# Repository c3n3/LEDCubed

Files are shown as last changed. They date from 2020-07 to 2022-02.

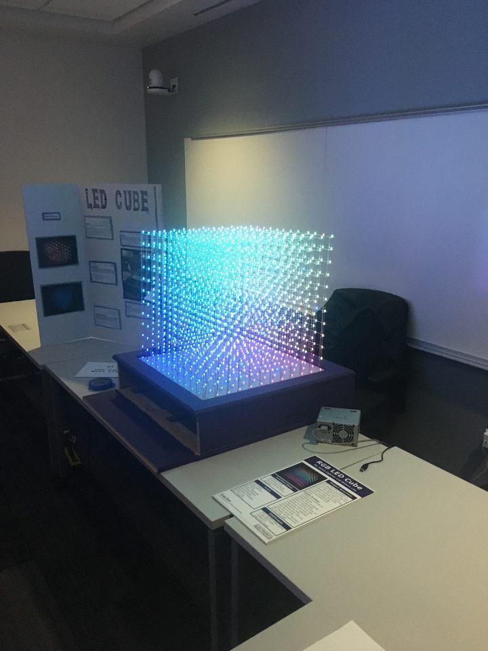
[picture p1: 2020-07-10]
kicad/LED_Cube/Documentation/Cube.jpg

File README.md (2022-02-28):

# LEDCubed
LED^3

Hello person who wishes to learn the cube's ways! This will be a BRIEF introduction... Basically the situation is as follows: we have a cube, it is a 12 x 12 x 12 cube of RGB LEDs, we have this newly (but probably old when your reading this) created softare architecture that will hopefully stand the test of time (you decide). The things you want to look into are:
  
  App.h -> this contains the workings for how you make an 'App' for the cube, these can be animations, games, anything...
  The contained class is to be used as an abstract class and not to be used directly.
  
  Basic_Functions.h -> these are the low level functions that allow you to turn LEDs on and change their colors and such

If you fully understand what is in those two files you can start making apps. If you have trouble understanding what is going on just contact me, Caden Churchman, if you can possibly get my information (I'm definitly not writting it here).  

*************************
If you want to bypass the whole structure of the code, feel free to comment out the main loop of arduino and just test stuff there. (Thats probably the best way to learn what the heck is going on)
*************************

TODO:
  - Nest (Wrires)

  - More cool animations

  - 3d tetris

  - 3d minesweeper <----------------------------------- NEXT

  - oscilating 3d graph

  - Glass box

  - Maze/DoomMaze

Done:
  - Add links or files for the KiCad files that made the circuitry

  - Optimize code - Done?

  - Rolling Text Display - Done: TypeEngine

  - Stand - Done
  
  - Power inside stand - Done

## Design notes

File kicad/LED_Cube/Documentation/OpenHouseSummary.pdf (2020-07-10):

Electronics Design Club LED Cube Project Summary

Objective
To create a 12x12x12 pixel, full-color, three-dimensional display.

Problem
Three-dimensional displays are ideal for any application dealing with the representation of real-world objects. These displays are very hard to build because they require light sources in a three-dimensional (3D) arrangement that are visible from any angle. Adding gradient or color effects to such a display further complicates the design because these features require a high degree of electrical manipulation.

Research
Extensive research was done on 3D displays to determine the most feasible design. The LED cube design was deemed most appropriate. Other types of 3D displays exist. One alternative design uses a fan-like structure with lights on spinning arms. This design takes advantage of the persistence of vision (POV) effect to generate 3D images. This design was deemed infeasible because of its mechanical intricacy.

Constraints
E-Club’s LED Cube was designed and constructed under the following constraints:
- 12x12x12 resolution
- Full-color operation
- No perceptible flicker
- Bright enough to be visible in a well-lit room
- Frame rate above 27 Hz
- Cost-effective

Solution
E-Club’s LED cube satisfies all of the original design criteria. It consists of a 12x12x12 matrix of full-color LEDs, multiplexing circuitry, and a microcontroller. The microcontroller is able to render images on the display via the multiplexing circuitry. Although the LEDs are multiplexed, they are still bright enough to be seen in virtually all lighting conditions.

Conclusion
The Electronics Design Club has constructed a full-color LED Cube consisting of 1728 multiplexed LEDs. This project is the result of two years of work by a team of students. The completion of the cube required extensive skill in soldering, woodworking, circuit design, programming, and troubleshooting. The end result is an impressive 3D display that showcases both the technical ability and creativity of K-State engineering students.

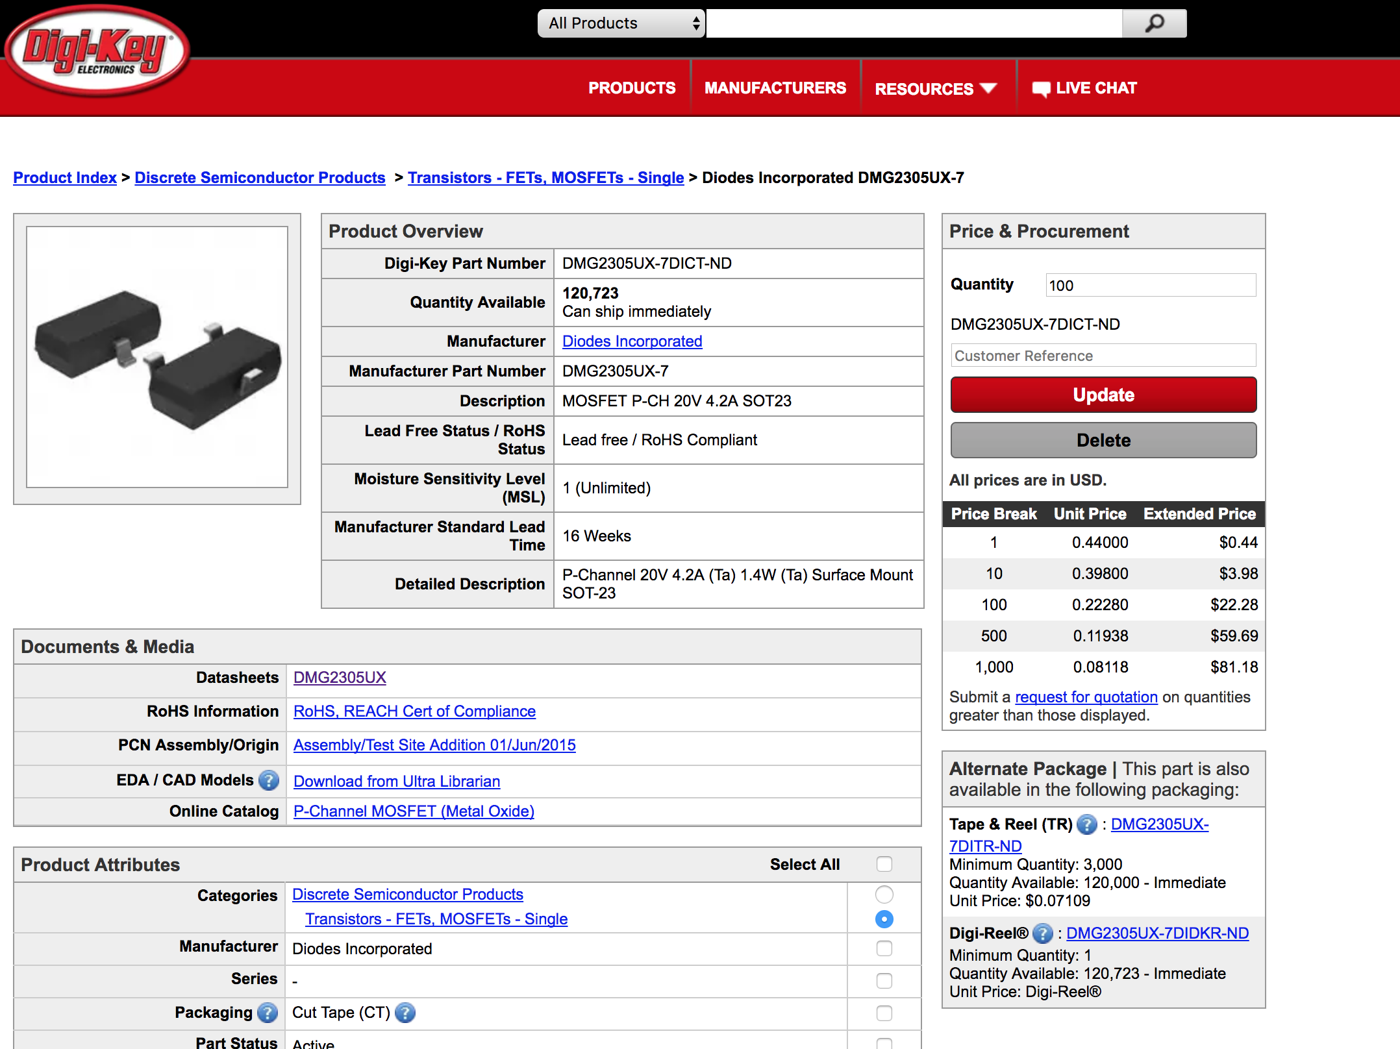
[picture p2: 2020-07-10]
kicad/LED_Cube/Documentation/Screen Shot 2017-12-16 at 11.59.10 PM.png

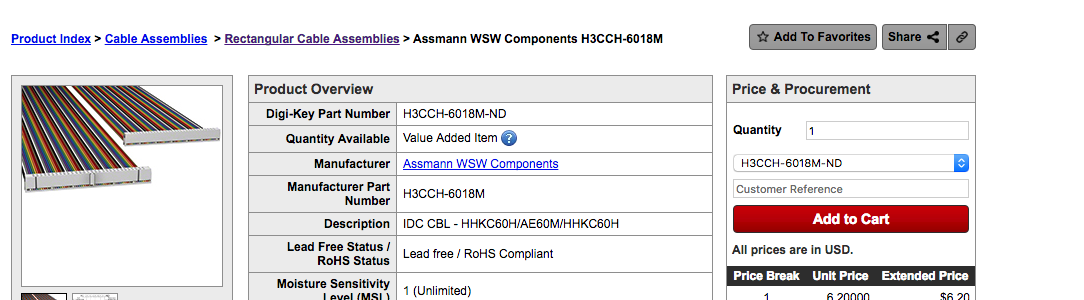
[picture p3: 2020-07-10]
kicad/LED_Cube/Screen Shot 2018-01-17 at 7.31.01 PM.png

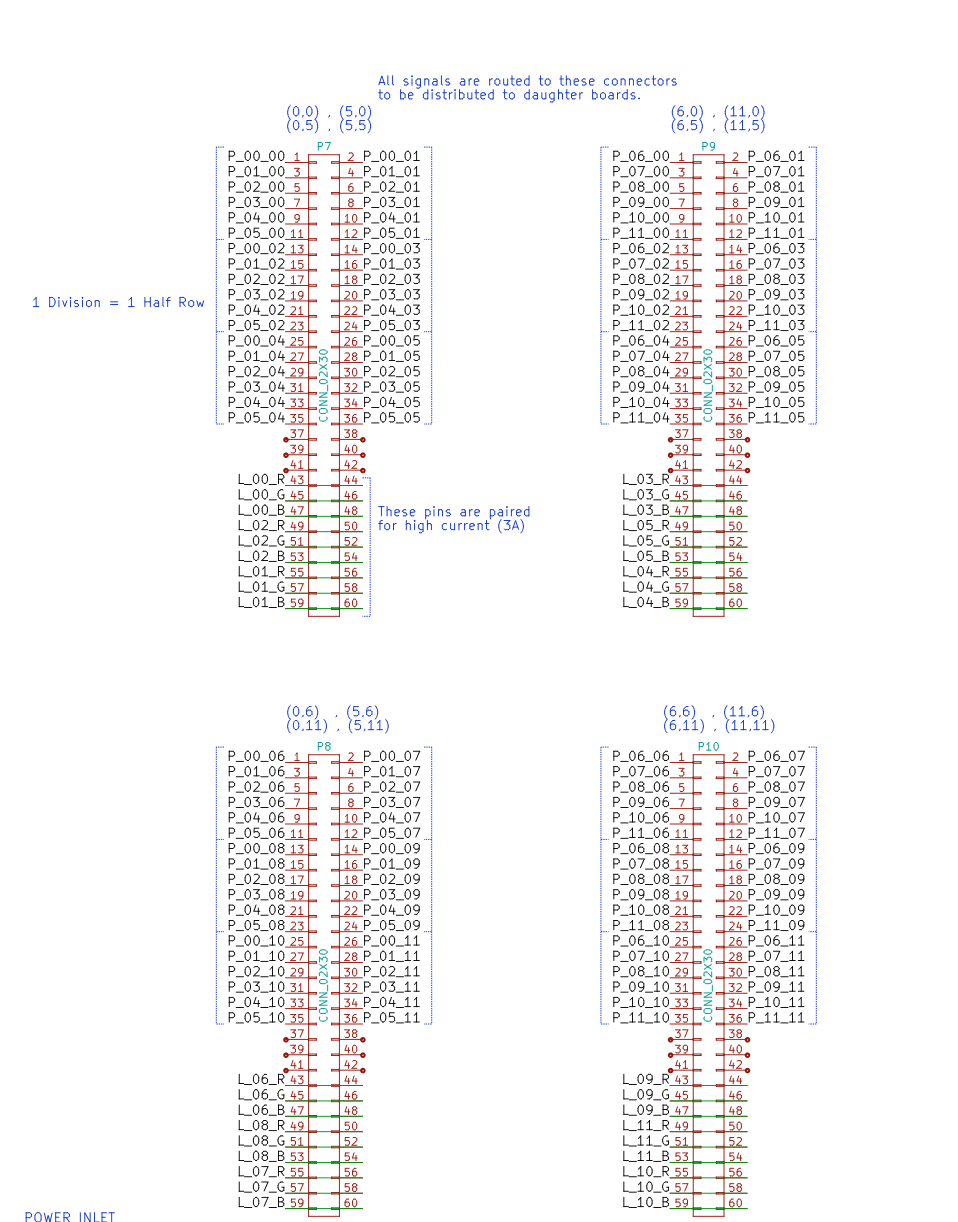
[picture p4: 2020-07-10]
kicad/LED_Cube/Screen Shot 2018-01-25 at 6.02.30 PM.png

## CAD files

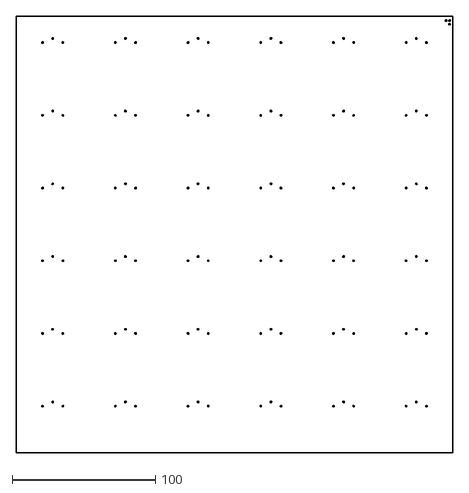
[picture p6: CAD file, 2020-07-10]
kicad/LED_Cube/CAD/LED Full Base TR.dxf
304.8 x 304.8

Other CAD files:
kicad/LED_Cube/CAD/LED Full Base TR.dwg

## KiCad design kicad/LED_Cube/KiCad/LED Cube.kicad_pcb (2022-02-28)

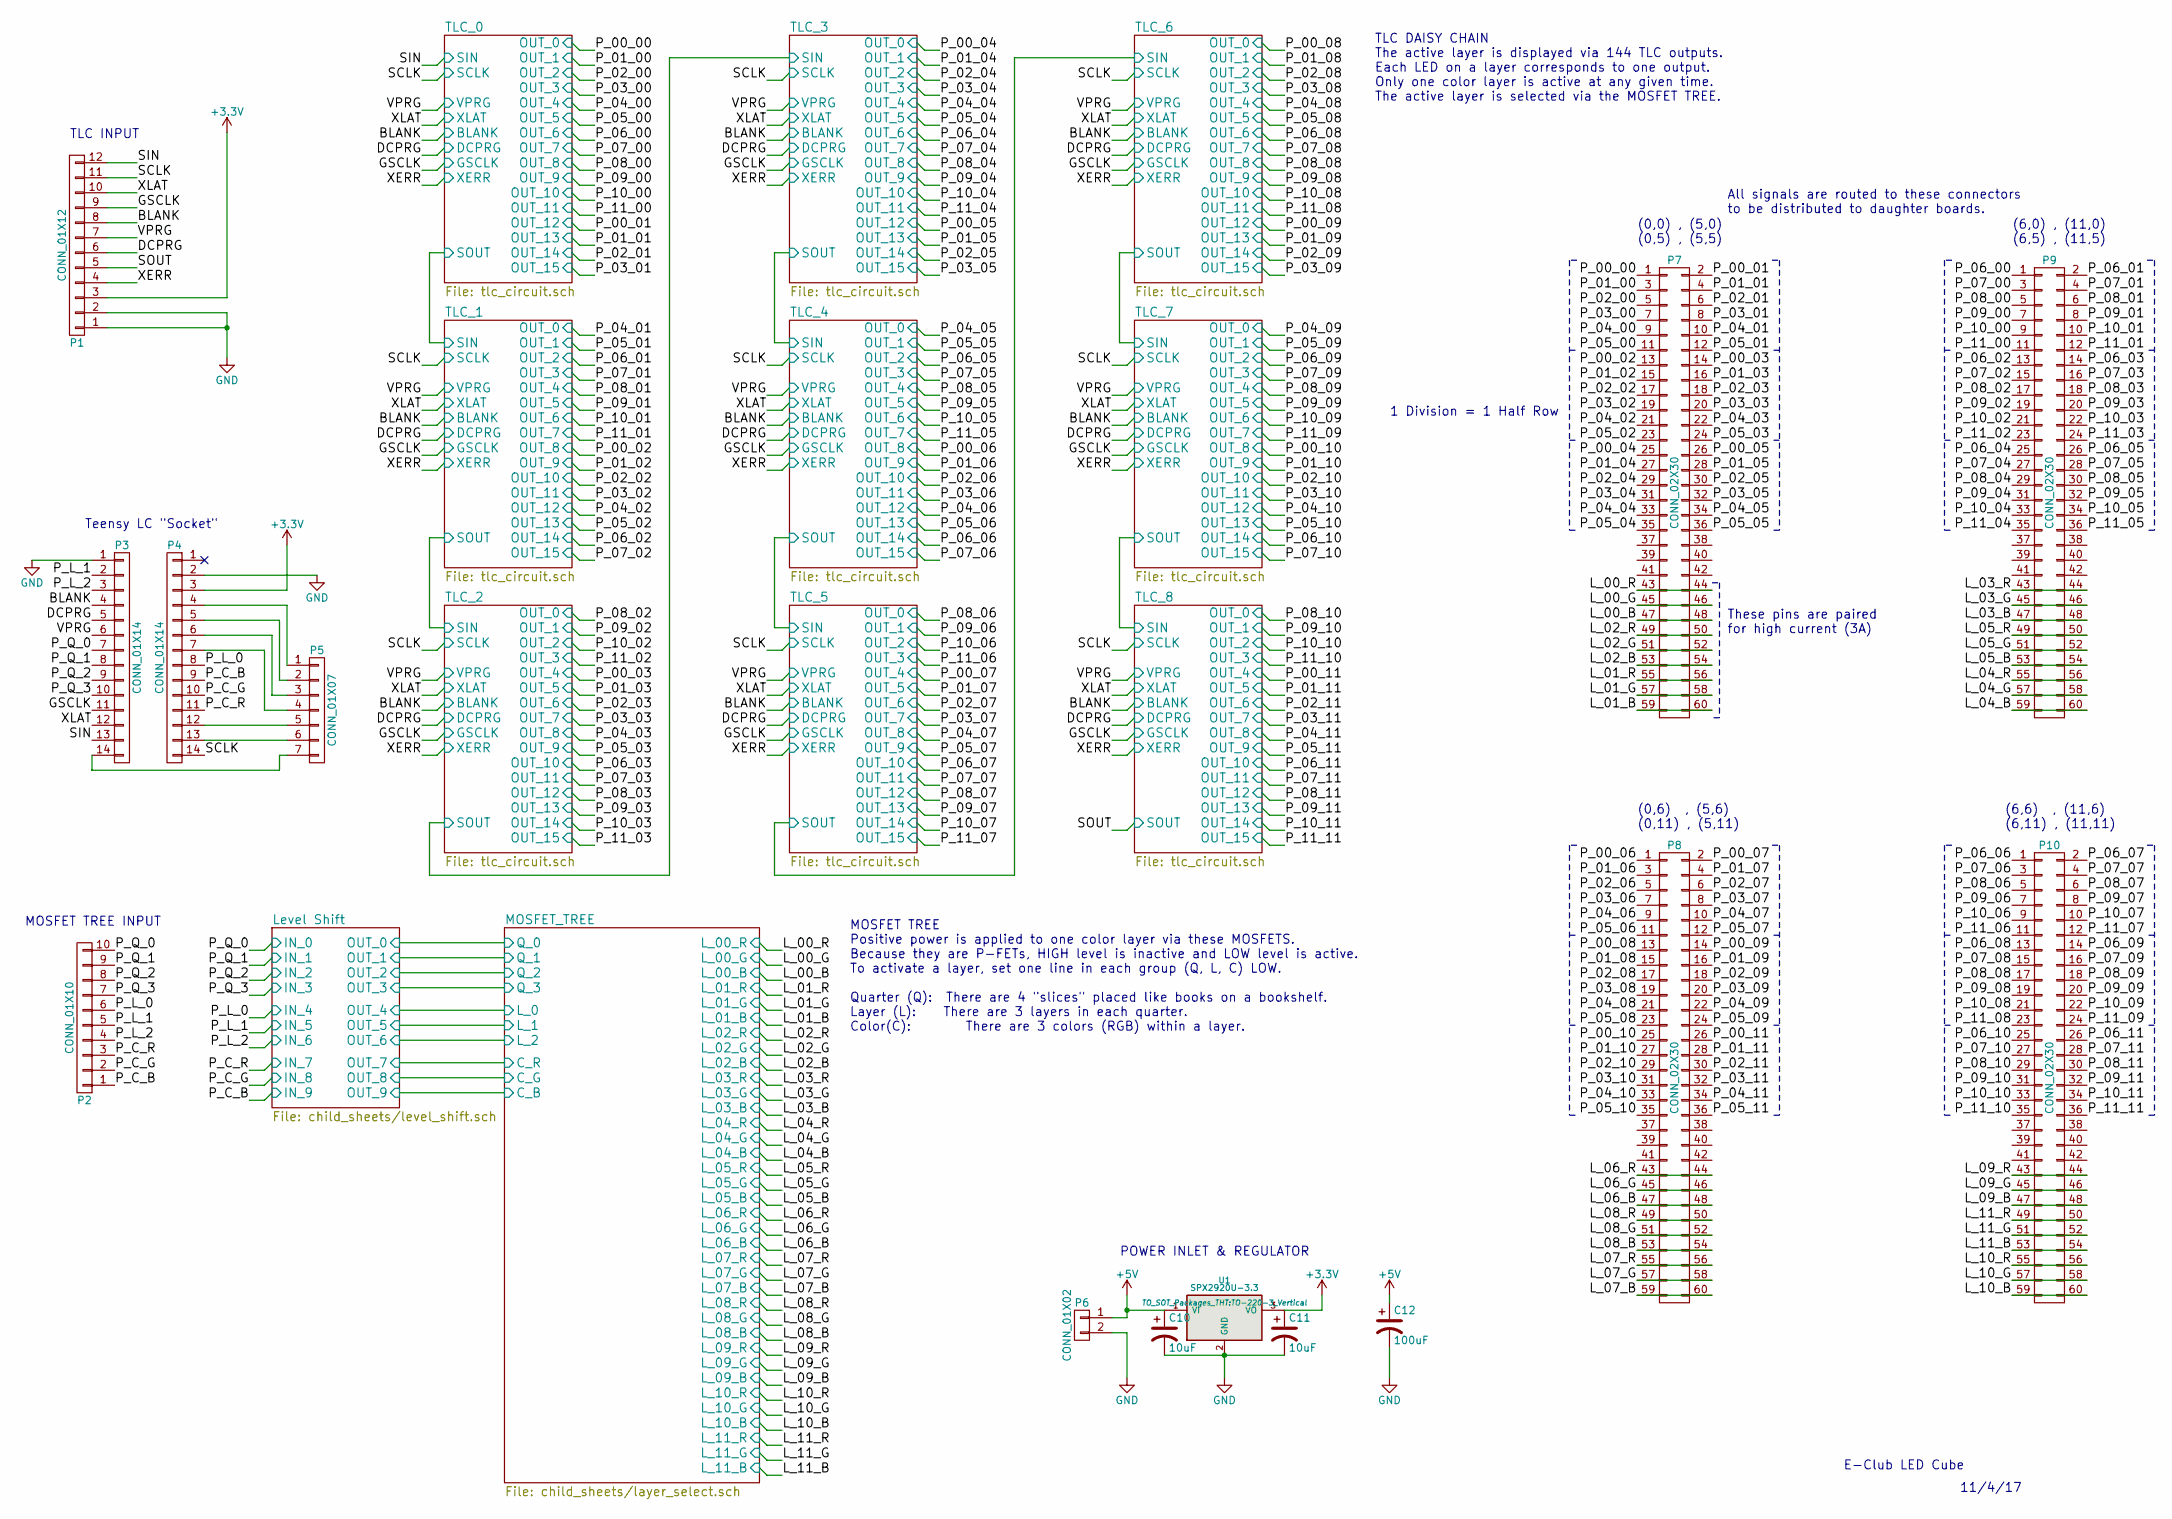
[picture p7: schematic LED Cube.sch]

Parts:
C10, C11: 10uF; CP_Radial_D5.0mm_P2.50mm
C12: 100uF; CP_Radial_D8.0mm_P3.50mm
P1: CONN_01X12; Pin_Header_Straight_1x12_Pitch2.54mm
P2: CONN_01X10; Pin_Header_Straight_1x10_Pitch2.54mm
P3, P4: CONN_01X14; Pin_Header_Straight_1x14_Pitch2.54mm
P5: CONN_01X07; Pin_Header_Straight_1x07_Pitch2.54mm
P6: CONN_01X02; TerminalBlock_bornier-2_P5.08mm
P7, P8, P9, P10: CONN_02X30; Pin_Header_Straight_2x30_Pitch2.54mm
U1: SPX2920U-3.3; TO-220-3_Vertical

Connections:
+3V3: C11.1, P1.3, P4.3, U1.3 (VO); also elsewhere on the board
+5V: C10.1, C12.1, P6.1, U1.1 (VI); also elsewhere on the board
/Level Shift/IN_0: P2.10, P3.7; also elsewhere on the board
/Level Shift/IN_1: P2.9, P3.8; also elsewhere on the board
/Level Shift/IN_2: P2.8, P3.9; also elsewhere on the board
/Level Shift/IN_3: P2.7, P3.10; also elsewhere on the board
/Level Shift/IN_4: P2.6, P4.8; also elsewhere on the board
/Level Shift/IN_5: P2.5, P3.2; also elsewhere on the board
/Level Shift/IN_6: P2.4, P3.3; also elsewhere on the board
/Level Shift/IN_7: P2.3, P4.11; also elsewhere on the board
/Level Shift/IN_8: P2.2, P4.10; also elsewhere on the board
/Level Shift/IN_9: P2.1, P4.9; also elsewhere on the board
/MOSFET_TREE/L_00_B: P7.47, P7.48; also elsewhere on the board
/MOSFET_TREE/L_00_G: P7.45, P7.46; also elsewhere on the board
/MOSFET_TREE/L_00_R: P7.43, P7.44; also elsewhere on the board
/MOSFET_TREE/L_01_B: P7.59, P7.60; also elsewhere on the board
/MOSFET_TREE/L_01_G: P7.57, P7.58; also elsewhere on the board
/MOSFET_TREE/L_01_R: P7.55, P7.56; also elsewhere on the board
/MOSFET_TREE/L_02_B: P7.53, P7.54; also elsewhere on the board
/MOSFET_TREE/L_02_G: P7.51, P7.52; also elsewhere on the board
/MOSFET_TREE/L_02_R: P7.49, P7.50; also elsewhere on the board
/MOSFET_TREE/L_03_B: P9.47, P9.48; also elsewhere on the board
/MOSFET_TREE/L_03_G: P9.45, P9.46; also elsewhere on the board
/MOSFET_TREE/L_03_R: P9.43, P9.44; also elsewhere on the board
/MOSFET_TREE/L_04_B: P9.59, P9.60; also elsewhere on the board
/MOSFET_TREE/L_04_G: P9.57, P9.58; also elsewhere on the board
/MOSFET_TREE/L_04_R: P9.55, P9.56; also elsewhere on the board
/MOSFET_TREE/L_05_B: P9.53, P9.54; also elsewhere on the board
/MOSFET_TREE/L_05_G: P9.51, P9.52; also elsewhere on the board
/MOSFET_TREE/L_05_R: P9.49, P9.50; also elsewhere on the board
/MOSFET_TREE/L_06_B: P8.47, P8.48; also elsewhere on the board
/MOSFET_TREE/L_06_G: P8.45, P8.46; also elsewhere on the board
/MOSFET_TREE/L_06_R: P8.43, P8.44; also elsewhere on the board
/MOSFET_TREE/L_07_B: P8.59, P8.60; also elsewhere on the board
/MOSFET_TREE/L_07_G: P8.57, P8.58; also elsewhere on the board
/MOSFET_TREE/L_07_R: P8.55, P8.56; also elsewhere on the board
/MOSFET_TREE/L_08_B: P8.53, P8.54; also elsewhere on the board
/MOSFET_TREE/L_08_G: P8.51, P8.52; also elsewhere on the board
/MOSFET_TREE/L_08_R: P8.49, P8.50; also elsewhere on the board
/MOSFET_TREE/L_09_B: P10.47, P10.48; also elsewhere on the board
/MOSFET_TREE/L_09_G: P10.45, P10.46; also elsewhere on the board
/MOSFET_TREE/L_09_R: P10.43, P10.44; also elsewhere on the board
/MOSFET_TREE/L_10_B: P10.59, P10.60; also elsewhere on the board
/MOSFET_TREE/L_10_G: P10.57, P10.58; also elsewhere on the board
/MOSFET_TREE/L_10_R: P10.55, P10.56; also elsewhere on the board
/MOSFET_TREE/L_11_B: P10.53, P10.54; also elsewhere on the board
/MOSFET_TREE/L_11_G: P10.51, P10.52; also elsewhere on the board
/MOSFET_TREE/L_11_R: P10.49, P10.50; also elsewhere on the board
/TLC_0/BLANK: P1.8, P3.4; also elsewhere on the board
/TLC_0/DCPRG: P1.6, P3.5; also elsewhere on the board
/TLC_0/GSCLK: P1.9, P3.11; also elsewhere on the board
/TLC_0/OUT_0: P7.1; also elsewhere on the board
/TLC_0/OUT_1: P7.3; also elsewhere on the board
/TLC_0/OUT_2: P7.5; also elsewhere on the board
/TLC_0/OUT_3: P7.7; also elsewhere on the board
/TLC_0/OUT_4: P7.9; also elsewhere on the board
/TLC_0/OUT_5: P7.11; also elsewhere on the board
/TLC_0/OUT_6: P9.1; also elsewhere on the board
/TLC_0/OUT_7: P9.3; also elsewhere on the board
/TLC_0/OUT_8: P9.5; also elsewhere on the board
/TLC_0/OUT_9: P9.7; also elsewhere on the board
/TLC_0/OUT_10: P9.9; also elsewhere on the board
/TLC_0/OUT_11: P9.11; also elsewhere on the board
/TLC_0/OUT_12: P7.2; also elsewhere on the board
/TLC_0/OUT_13: P7.4; also elsewhere on the board
/TLC_0/OUT_14: P7.6; also elsewhere on the board
/TLC_0/OUT_15: P7.8; also elsewhere on the board
/TLC_0/SCLK: P1.11, P4.14; also elsewhere on the board
/TLC_0/SIN: P1.12, P3.13; also elsewhere on the board
/TLC_0/VPRG: P1.7, P3.6; also elsewhere on the board
/TLC_0/XERR: P1.4; also elsewhere on the board
/TLC_0/XLAT: P1.10, P3.12; also elsewhere on the board
/TLC_1/OUT_0: P7.10; also elsewhere on the board
/TLC_1/OUT_1: P7.12; also elsewhere on the board
/TLC_1/OUT_2: P9.2; also elsewhere on the board
/TLC_1/OUT_3: P9.4; also elsewhere on the board
/TLC_1/OUT_4: P9.6; also elsewhere on the board
/TLC_1/OUT_5: P9.8; also elsewhere on the board
/TLC_1/OUT_6: P9.10; also elsewhere on the board
/TLC_1/OUT_7: P9.12; also elsewhere on the board
/TLC_1/OUT_8: P7.13; also elsewhere on the board
/TLC_1/OUT_9: P7.15; also elsewhere on the board
/TLC_1/OUT_10: P7.17; also elsewhere on the board
/TLC_1/OUT_11: P7.19; also elsewhere on the board
/TLC_1/OUT_12: P7.21; also elsewhere on the board
/TLC_1/OUT_13: P7.23; also elsewhere on the board
/TLC_1/OUT_14: P9.13; also elsewhere on the board
/TLC_1/OUT_15: P9.15; also elsewhere on the board
/TLC_2/OUT_0: P9.17; also elsewhere on the board
/TLC_2/OUT_1: P9.19; also elsewhere on the board
/TLC_2/OUT_2: P9.21; also elsewhere on the board
/TLC_2/OUT_3: P9.23; also elsewhere on the board
/TLC_2/OUT_4: P7.14; also elsewhere on the board
/TLC_2/OUT_5: P7.16; also elsewhere on the board
/TLC_2/OUT_6: P7.18; also elsewhere on the board
/TLC_2/OUT_7: P7.20; also elsewhere on the board
/TLC_2/OUT_8: P7.22; also elsewhere on the board
/TLC_2/OUT_9: P7.24; also elsewhere on the board
/TLC_2/OUT_10: P9.14; also elsewhere on the board
/TLC_2/OUT_11: P9.16; also elsewhere on the board
/TLC_2/OUT_12: P9.18; also elsewhere on the board
/TLC_2/OUT_13: P9.20; also elsewhere on the board
/TLC_2/OUT_14: P9.22; also elsewhere on the board
/TLC_2/OUT_15: P9.24; also elsewhere on the board
/TLC_3/OUT_0: P7.25; also elsewhere on the board
/TLC_3/OUT_1: P7.27; also elsewhere on the board
/TLC_3/OUT_2: P7.29; also elsewhere on the board
/TLC_3/OUT_3: P7.31; also elsewhere on the board
/TLC_3/OUT_4: P7.33; also elsewhere on the board
/TLC_3/OUT_5: P7.35; also elsewhere on the board
/TLC_3/OUT_6: P9.25; also elsewhere on the board
/TLC_3/OUT_7: P9.27; also elsewhere on the board
/TLC_3/OUT_8: P9.29; also elsewhere on the board
/TLC_3/OUT_9: P9.31; also elsewhere on the board
/TLC_3/OUT_10: P9.33; also elsewhere on the board
/TLC_3/OUT_11: P9.35; also elsewhere on the board
/TLC_3/OUT_12: P7.26; also elsewhere on the board
/TLC_3/OUT_13: P7.28; also elsewhere on the board
/TLC_3/OUT_14: P7.30; also elsewhere on the board
/TLC_3/OUT_15: P7.32; also elsewhere on the board
/TLC_4/OUT_0: P7.34; also elsewhere on the board
/TLC_4/OUT_1: P7.36; also elsewhere on the board
/TLC_4/OUT_2: P9.26; also elsewhere on the board
/TLC_4/OUT_3: P9.28; also elsewhere on the board
/TLC_4/OUT_4: P9.30; also elsewhere on the board
/TLC_4/OUT_5: P9.32; also elsewhere on the board
/TLC_4/OUT_6: P9.34; also elsewhere on the board
/TLC_4/OUT_7: P9.36; also elsewhere on the board
/TLC_4/OUT_8: P8.1; also elsewhere on the board
/TLC_4/OUT_9: P8.3; also elsewhere on the board
/TLC_4/OUT_10: P8.5; also elsewhere on the board
/TLC_4/OUT_11: P8.7; also elsewhere on the board
/TLC_4/OUT_12: P8.9; also elsewhere on the board
/TLC_4/OUT_13: P8.11; also elsewhere on the board
/TLC_4/OUT_14: P10.1; also elsewhere on the board
/TLC_4/OUT_15: P10.3; also elsewhere on the board
/TLC_5/OUT_0: P10.5; also elsewhere on the board
/TLC_5/OUT_1: P10.7; also elsewhere on the board
/TLC_5/OUT_2: P10.9; also elsewhere on the board
/TLC_5/OUT_3: P10.11; also elsewhere on the board
/TLC_5/OUT_4: P8.2; also elsewhere on the board
/TLC_5/OUT_5: P8.4; also elsewhere on the board
/TLC_5/OUT_6: P8.6; also elsewhere on the board
/TLC_5/OUT_7: P8.8; also elsewhere on the board
/TLC_5/OUT_8: P8.10; also elsewhere on the board
/TLC_5/OUT_9: P8.12; also elsewhere on the board
/TLC_5/OUT_10: P10.2; also elsewhere on the board
/TLC_5/OUT_11: P10.4; also elsewhere on the board
/TLC_5/OUT_12: P10.6; also elsewhere on the board
/TLC_5/OUT_13: P10.8; also elsewhere on the board
/TLC_5/OUT_14: P10.10; also elsewhere on the board
/TLC_5/OUT_15: P10.12; also elsewhere on the board
/TLC_6/OUT_0: P8.13; also elsewhere on the board
/TLC_6/OUT_1: P8.15; also elsewhere on the board
/TLC_6/OUT_2: P8.17; also elsewhere on the board
/TLC_6/OUT_3: P8.19; also elsewhere on the board
/TLC_6/OUT_4: P8.21; also elsewhere on the board
/TLC_6/OUT_5: P8.23; also elsewhere on the board
/TLC_6/OUT_6: P10.13; also elsewhere on the board
/TLC_6/OUT_7: P10.15; also elsewhere on the board
/TLC_6/OUT_8: P10.17; also elsewhere on the board
/TLC_6/OUT_9: P10.19; also elsewhere on the board
/TLC_6/OUT_10: P10.21; also elsewhere on the board
/TLC_6/OUT_11: P10.23; also elsewhere on the board
/TLC_6/OUT_12: P8.14; also elsewhere on the board
/TLC_6/OUT_13: P8.16; also elsewhere on the board
/TLC_6/OUT_14: P8.18; also elsewhere on the board
/TLC_6/OUT_15: P8.20; also elsewhere on the board
/TLC_7/OUT_0: P8.22; also elsewhere on the board
/TLC_7/OUT_1: P8.24; also elsewhere on the board
/TLC_7/OUT_2: P10.14; also elsewhere on the board
/TLC_7/OUT_3: P10.16; also elsewhere on the board
/TLC_7/OUT_4: P10.18; also elsewhere on the board
/TLC_7/OUT_5: P10.20; also elsewhere on the board
/TLC_7/OUT_6: P10.22; also elsewhere on the board
/TLC_7/OUT_7: P10.24; also elsewhere on the board
/TLC_7/OUT_8: P8.25; also elsewhere on the board
/TLC_7/OUT_9: P8.27; also elsewhere on the board
/TLC_7/OUT_10: P8.29; also elsewhere on the board
/TLC_7/OUT_11: P8.31; also elsewhere on the board
/TLC_7/OUT_12: P8.33; also elsewhere on the board
/TLC_7/OUT_13: P8.35; also elsewhere on the board
/TLC_7/OUT_14: P10.25; also elsewhere on the board
/TLC_7/OUT_15: P10.27; also elsewhere on the board
/TLC_8/OUT_0: P10.29; also elsewhere on the board
/TLC_8/OUT_1: P10.31; also elsewhere on the board
/TLC_8/OUT_2: P10.33; also elsewhere on the board
/TLC_8/OUT_3: P10.35; also elsewhere on the board
/TLC_8/OUT_4: P8.26; also elsewhere on the board
/TLC_8/OUT_5: P8.28; also elsewhere on the board
/TLC_8/OUT_6: P8.30; also elsewhere on the board
/TLC_8/OUT_7: P8.32; also elsewhere on the board
/TLC_8/OUT_8: P8.34; also elsewhere on the board
/TLC_8/OUT_9: P8.36; also elsewhere on the board
/TLC_8/OUT_10: P10.26; also elsewhere on the board
/TLC_8/OUT_11: P10.28; also elsewhere on the board
/TLC_8/OUT_12: P10.30; also elsewhere on the board
/TLC_8/OUT_13: P10.32; also elsewhere on the board
/TLC_8/OUT_14: P10.34; also elsewhere on the board
/TLC_8/OUT_15: P10.36; also elsewhere on the board
/TLC_8/SOUT: P1.5; also elsewhere on the board
GND: C10.2, C11.2, C12.2, P1.1, P1.2, P3.1, P4.2, P6.2, U1.2 (GND); also elsewhere on the board
unnamed: P3.14, P5.7
unnamed: P4.4, P5.1
unnamed: P4.5, P5.2
unnamed: P4.6, P5.3
unnamed: P4.7, P5.4
unnamed: P4.12, P5.5
unnamed: P4.13, P5.6

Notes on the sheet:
E-Club LED Cube
11/4/17
(0,0) , (5,0) (0,5) , (5,5)
(6,0) , (11,0) (6,5) , (11,5)
(0,6) , (5,6) (0,11) , (5,11)
(6,6) , (11,6) (6,11) , (11,11)
MOSFET TREE Positive power is applied to one color layer via these MOSFETS. Because they are P-FETs, HIGH level is inactive and LOW level is active. To activate a layer, set one line in each group (Q, L, C) LOW. Quarter (Q): There are 4 "slices" placed like books on a bookshelf. Layer (L): There ar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
TLC DAISY CHAIN The active layer is displayed via 144 TLC outputs. Each LED on a layer corresponds to one output. Only one color layer is active at any given time. The active layer is selected via the MOSFET TREE.
All signals are routed to these connectors to be distributed to daughter boards.
POWER INLET & REGULATOR
TLC INPUT
MOSFET TREE INPUT
1 Division = 1 Half Row
Teensy LC "Socket"
These pins are paired for high current (3A)

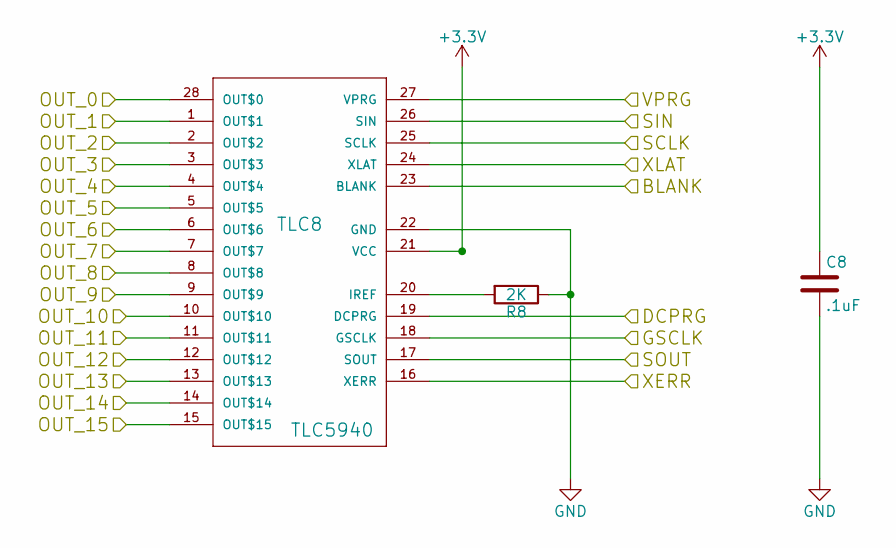
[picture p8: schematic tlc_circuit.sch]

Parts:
C1: .1uF; R_0805_HandSoldering
R1: 2K; R_0805_HandSoldering
TLC4: TLC5940; DIP-28_W7.62mm_Socket

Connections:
+3V3: C1.1, TLC4.21 (VCC); also elsewhere on the board
/TLC_0/BLANK: TLC4.23 (BLANK); also elsewhere on the board
/TLC_0/DCPRG: TLC4.19 (DCPRG); also elsewhere on the board
/TLC_0/GSCLK: TLC4.18 (GSCLK); also elsewhere on the board
/TLC_0/SCLK: TLC4.25 (SCLK); also elsewhere on the board
/TLC_0/VPRG: TLC4.27 (VPRG); also elsewhere on the board
/TLC_0/XERR: TLC4.16 (XERR); also elsewhere on the board
/TLC_0/XLAT: TLC4.24 (XLAT); also elsewhere on the board
/TLC_3/OUT_0: TLC4.28 (OUT$0); also elsewhere on the board
/TLC_3/OUT_1: TLC4.1 (OUT$1); also elsewhere on the board
/TLC_3/OUT_2: TLC4.2 (OUT$2); also elsewhere on the board
/TLC_3/OUT_3: TLC4.3 (OUT$3); also elsewhere on the board
/TLC_3/OUT_4: TLC4.4 (OUT$4); also elsewhere on the board
/TLC_3/OUT_5: TLC4.5 (OUT$5); also elsewhere on the board
/TLC_3/OUT_6: TLC4.6 (OUT$6); also elsewhere on the board
/TLC_3/OUT_7: TLC4.7 (OUT$7); also elsewhere on the board
/TLC_3/OUT_8: TLC4.8 (OUT$8); also elsewhere on the board
/TLC_3/OUT_9: TLC4.9 (OUT$9); also elsewhere on the board
/TLC_3/OUT_10: TLC4.10 (OUT$10); also elsewhere on the board
/TLC_3/OUT_11: TLC4.11 (OUT$11); also elsewhere on the board
/TLC_3/OUT_12: TLC4.12 (OUT$12); also elsewhere on the board
/TLC_3/OUT_13: TLC4.13 (OUT$13); also elsewhere on the board
/TLC_3/OUT_14: TLC4.14 (OUT$14); also elsewhere on the board
/TLC_3/OUT_15: TLC4.15 (OUT$15); also elsewhere on the board
/TLC_3/SIN: TLC4.26 (SIN); also elsewhere on the board
/TLC_4/SIN: TLC4.17 (SOUT); also elsewhere on the board
GND: C1.2, R1.1, TLC4.22 (GND); also elsewhere on the board

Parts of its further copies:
C2, C3, C4, C5, C6, C7, C8, C9: .1uF; R_0805_HandSoldering
R2, R3, R4, R5, R6, R7, R8, R9: 2K; R_0805_HandSoldering
TLC1, TLC2, TLC3, TLC5, TLC6, TLC7, TLC8, TLC9: TLC5940; DIP-28_W7.62mm_Socket

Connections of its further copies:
+3V3: C2.1, C3.1, C4.1, C5.1, C6.1, C7.1, C8.1, C9.1, TLC1.21 (VCC), TLC2.21 (VCC), TLC3.21 (VCC), TLC5.21 (VCC), TLC6.21 (VCC), TLC7.21 (VCC), TLC8.21 (VCC), TLC9.21 (VCC); also elsewhere on the board
/TLC_0/BLANK: TLC1.23 (BLANK), TLC2.23 (BLANK), TLC3.23 (BLANK), TLC5.23 (BLANK), TLC6.23 (BLANK), TLC7.23 (BLANK), TLC8.23 (BLANK), TLC9.23 (BLANK); also elsewhere on the board
/TLC_0/DCPRG: TLC1.19 (DCPRG), TLC2.19 (DCPRG), TLC3.19 (DCPRG), TLC5.19 (DCPRG), TLC6.19 (DCPRG), TLC7.19 (DCPRG), TLC8.19 (DCPRG), TLC9.19 (DCPRG); also elsewhere on the board
/TLC_0/GSCLK: TLC1.18 (GSCLK), TLC2.18 (GSCLK), TLC3.18 (GSCLK), TLC5.18 (GSCLK), TLC6.18 (GSCLK), TLC7.18 (GSCLK), TLC8.18 (GSCLK), TLC9.18 (GSCLK); also elsewhere on the board
/TLC_0/OUT_0: TLC1.28 (OUT$0); also elsewhere on the board
/TLC_0/OUT_1: TLC1.1 (OUT$1); also elsewhere on the board
/TLC_0/OUT_2: TLC1.2 (OUT$2); also elsewhere on the board
/TLC_0/OUT_3: TLC1.3 (OUT$3); also elsewhere on the board
/TLC_0/OUT_4: TLC1.4 (OUT$4); also elsewhere on the board
/TLC_0/OUT_5: TLC1.5 (OUT$5); also elsewhere on the board
/TLC_0/OUT_6: TLC1.6 (OUT$6); also elsewhere on the board
/TLC_0/OUT_7: TLC1.7 (OUT$7); also elsewhere on the board
/TLC_0/OUT_8: TLC1.8 (OUT$8); also elsewhere on the board
/TLC_0/OUT_9: TLC1.9 (OUT$9); also elsewhere on the board
/TLC_0/OUT_10: TLC1.10 (OUT$10); also elsewhere on the board
/TLC_0/OUT_11: TLC1.11 (OUT$11); also elsewhere on the board
/TLC_0/OUT_12: TLC1.12 (OUT$12); also elsewhere on the board
/TLC_0/OUT_13: TLC1.13 (OUT$13); also elsewhere on the board
/TLC_0/OUT_14: TLC1.14 (OUT$14); also elsewhere on the board
/TLC_0/OUT_15: TLC1.15 (OUT$15); also elsewhere on the board
/TLC_0/SCLK: TLC1.25 (SCLK), TLC2.25 (SCLK), TLC3.25 (SCLK), TLC5.25 (SCLK), TLC6.25 (SCLK), TLC7.25 (SCLK), TLC8.25 (SCLK), TLC9.25 (SCLK); also elsewhere on the board
/TLC_0/SIN: TLC1.26 (SIN); also elsewhere on the board
/TLC_0/VPRG: TLC1.27 (VPRG), TLC2.27 (VPRG), TLC3.27 (VPRG), TLC5.27 (VPRG), TLC6.27 (VPRG), TLC7.27 (VPRG), TLC8.27 (VPRG), TLC9.27 (VPRG); also elsewhere on the board
/TLC_0/XERR: TLC1.16 (XERR), TLC2.16 (XERR), TLC3.16 (XERR), TLC5.16 (XERR), TLC6.16 (XERR), TLC7.16 (XERR), TLC8.16 (XERR), TLC9.16 (XERR); also elsewhere on the board
/TLC_0/XLAT: TLC1.24 (XLAT), TLC2.24 (XLAT), TLC3.24 (XLAT), TLC5.24 (XLAT), TLC6.24 (XLAT), TLC7.24 (XLAT), TLC8.24 (XLAT), TLC9.24 (XLAT); also elsewhere on the board
/TLC_1/OUT_0: TLC2.28 (OUT$0); also elsewhere on the board
/TLC_1/OUT_1: TLC2.1 (OUT$1); also elsewhere on the board
/TLC_1/OUT_2: TLC2.2 (OUT$2); also elsewhere on the board
/TLC_1/OUT_3: TLC2.3 (OUT$3); also elsewhere on the board
/TLC_1/OUT_4: TLC2.4 (OUT$4); also elsewhere on the board
/TLC_1/OUT_5: TLC2.5 (OUT$5); also elsewhere on the board
/TLC_1/OUT_6: TLC2.6 (OUT$6); also elsewhere on the board
/TLC_1/OUT_7: TLC2.7 (OUT$7); also elsewhere on the board
/TLC_1/OUT_8: TLC2.8 (OUT$8); also elsewhere on the board
/TLC_1/OUT_9: TLC2.9 (OUT$9); also elsewhere on the board
/TLC_1/OUT_10: TLC2.10 (OUT$10); also elsewhere on the board
/TLC_1/OUT_11: TLC2.11 (OUT$11); also elsewhere on the board
/TLC_1/OUT_12: TLC2.12 (OUT$12); also elsewhere on the board
/TLC_1/OUT_13: TLC2.13 (OUT$13); also elsewhere on the board
/TLC_1/OUT_14: TLC2.14 (OUT$14); also elsewhere on the board
/TLC_1/OUT_15: TLC2.15 (OUT$15); also elsewhere on the board
/TLC_1/SIN: TLC1.17 (SOUT), TLC2.26 (SIN)
/TLC_2/OUT_0: TLC3.28 (OUT$0); also elsewhere on the board
/TLC_2/OUT_1: TLC3.1 (OUT$1); also elsewhere on the board
/TLC_2/OUT_2: TLC3.2 (OUT$2); also elsewhere on the board
/TLC_2/OUT_3: TLC3.3 (OUT$3); also elsewhere on the board
/TLC_2/OUT_4: TLC3.4 (OUT$4); also elsewhere on the board
/TLC_2/OUT_5: TLC3.5 (OUT$5); also elsewhere on the board
/TLC_2/OUT_6: TLC3.6 (OUT$6); also elsewhere on the board
/TLC_2/OUT_7: TLC3.7 (OUT$7); also elsewhere on the board
/TLC_2/OUT_8: TLC3.8 (OUT$8); also elsewhere on the board
/TLC_2/OUT_9: TLC3.9 (OUT$9); also elsewhere on the board
/TLC_2/OUT_10: TLC3.10 (OUT$10); also elsewhere on the board
/TLC_2/OUT_11: TLC3.11 (OUT$11); also elsewhere on the board
/TLC_2/OUT_12: TLC3.12 (OUT$12); also elsewhere on the board
/TLC_2/OUT_13: TLC3.13 (OUT$13); also elsewhere on the board
/TLC_2/OUT_14: TLC3.14 (OUT$14); also elsewhere on the board
/TLC_2/OUT_15: TLC3.15 (OUT$15); also elsewhere on the board
/TLC_2/SIN: TLC2.17 (SOUT), TLC3.26 (SIN)
/TLC_3/SIN: TLC3.17 (SOUT); also elsewhere on the board
/TLC_4/OUT_0: TLC5.28 (OUT$0); also elsewhere on the board
/TLC_4/OUT_1: TLC5.1 (OUT$1); also elsewhere on the board
/TLC_4/OUT_2: TLC5.2 (OUT$2); also elsewhere on the board
/TLC_4/OUT_3: TLC5.3 (OUT$3); also elsewhere on the board
/TLC_4/OUT_4: TLC5.4 (OUT$4); also elsewhere on the board
/TLC_4/OUT_5: TLC5.5 (OUT$5); also elsewhere on the board
/TLC_4/OUT_6: TLC5.6 (OUT$6); also elsewhere on the board
/TLC_4/OUT_7: TLC5.7 (OUT$7); also elsewhere on the board
/TLC_4/OUT_8: TLC5.8 (OUT$8); also elsewhere on the board
/TLC_4/OUT_9: TLC5.9 (OUT$9); also elsewhere on the board
/TLC_4/OUT_10: TLC5.10 (OUT$10); also elsewhere on the board
/TLC_4/OUT_11: TLC5.11 (OUT$11); also elsewhere on the board
/TLC_4/OUT_12: TLC5.12 (OUT$12); also elsewhere on the board
/TLC_4/OUT_13: TLC5.13 (OUT$13); also elsewhere on the board
/TLC_4/OUT_14: TLC5.14 (OUT$14); also elsewhere on the board
/TLC_4/OUT_15: TLC5.15 (OUT$15); also elsewhere on the board
/TLC_4/SIN: TLC5.26 (SIN); also elsewhere on the board
/TLC_5/OUT_0: TLC6.28 (OUT$0); also elsewhere on the board
/TLC_5/OUT_1: TLC6.1 (OUT$1); also elsewhere on the board
/TLC_5/OUT_2: TLC6.2 (OUT$2); also elsewhere on the board
/TLC_5/OUT_3: TLC6.3 (OUT$3); also elsewhere on the board
/TLC_5/OUT_4: TLC6.4 (OUT$4); also elsewhere on the board
/TLC_5/OUT_5: TLC6.5 (OUT$5); also elsewhere on the board
/TLC_5/OUT_6: TLC6.6 (OUT$6); also elsewhere on the board
/TLC_5/OUT_7: TLC6.7 (OUT$7); also elsewhere on the board
/TLC_5/OUT_8: TLC6.8 (OUT$8); also elsewhere on the board
/TLC_5/OUT_9: TLC6.9 (OUT$9); also elsewhere on the board
/TLC_5/OUT_10: TLC6.10 (OUT$10); also elsewhere on the board
/TLC_5/OUT_11: TLC6.11 (OUT$11); also elsewhere on the board
/TLC_5/OUT_12: TLC6.12 (OUT$12); also elsewhere on the board
/TLC_5/OUT_13: TLC6.13 (OUT$13); also elsewhere on the board
/TLC_5/OUT_14: TLC6.14 (OUT$14); also elsewhere on the board
/TLC_5/OUT_15: TLC6.15 (OUT$15); also elsewhere on the board
/TLC_5/SIN: TLC5.17 (SOUT), TLC6.26 (SIN)
/TLC_6/OUT_0: TLC7.28 (OUT$0); also elsewhere on the board
/TLC_6/OUT_1: TLC7.1 (OUT$1); also elsewhere on the board
/TLC_6/OUT_2: TLC7.2 (OUT$2); also elsewhere on the board
/TLC_6/OUT_3: TLC7.3 (OUT$3); also elsewhere on the board
/TLC_6/OUT_4: TLC7.4 (OUT$4); also elsewhere on the board
/TLC_6/OUT_5: TLC7.5 (OUT$5); also elsewhere on the board
/TLC_6/OUT_6: TLC7.6 (OUT$6); also elsewhere on the board
/TLC_6/OUT_7: TLC7.7 (OUT$7); also elsewhere on the board
/TLC_6/OUT_8: TLC7.8 (OUT$8); also elsewhere on the board
/TLC_6/OUT_9: TLC7.9 (OUT$9); also elsewhere on the board
/TLC_6/OUT_10: TLC7.10 (OUT$10); also elsewhere on the board
/TLC_6/OUT_11: TLC7.11 (OUT$11); also elsewhere on the board
/TLC_6/OUT_12: TLC7.12 (OUT$12); also elsewhere on the board
/TLC_6/OUT_13: TLC7.13 (OUT$13); also elsewhere on the board
/TLC_6/OUT_14: TLC7.14 (OUT$14); also elsewhere on the board
/TLC_6/OUT_15: TLC7.15 (OUT$15); also elsewhere on the board
/TLC_6/SIN: TLC6.17 (SOUT), TLC7.26 (SIN)
/TLC_7/OUT_0: TLC8.28 (OUT$0); also elsewhere on the board
/TLC_7/OUT_1: TLC8.1 (OUT$1); also elsewhere on the board
/TLC_7/OUT_2: TLC8.2 (OUT$2); also elsewhere on the board
/TLC_7/OUT_3: TLC8.3 (OUT$3); also elsewhere on the board
/TLC_7/OUT_4: TLC8.4 (OUT$4); also elsewhere on the board
/TLC_7/OUT_5: TLC8.5 (OUT$5); also elsewhere on the board
/TLC_7/OUT_6: TLC8.6 (OUT$6); also elsewhere on the board
/TLC_7/OUT_7: TLC8.7 (OUT$7); also elsewhere on the board
/TLC_7/OUT_8: TLC8.8 (OUT$8); also elsewhere on the board
/TLC_7/OUT_9: TLC8.9 (OUT$9); also elsewhere on the board
/TLC_7/OUT_10: TLC8.10 (OUT$10); also elsewhere on the board
/TLC_7/OUT_11: TLC8.11 (OUT$11); also elsewhere on the board
/TLC_7/OUT_12: TLC8.12 (OUT$12); also elsewhere on the board
/TLC_7/OUT_13: TLC8.13 (OUT$13); also elsewhere on the board
/TLC_7/OUT_14: TLC8.14 (OUT$14); also elsewhere on the board
/TLC_7/OUT_15: TLC8.15 (OUT$15); also elsewhere on the board
/TLC_7/SIN: TLC7.17 (SOUT), TLC8.26 (SIN)
/TLC_8/OUT_0: TLC9.28 (OUT$0); also elsewhere on the board
/TLC_8/OUT_1: TLC9.1 (OUT$1); also elsewhere on the board
/TLC_8/OUT_2: TLC9.2 (OUT$2); also elsewhere on the board
/TLC_8/OUT_3: TLC9.3 (OUT$3); also elsewhere on the board
/TLC_8/OUT_4: TLC9.4 (OUT$4); also elsewhere on the board
/TLC_8/OUT_5: TLC9.5 (OUT$5); also elsewhere on the board
/TLC_8/OUT_6: TLC9.6 (OUT$6); also elsewhere on the board
/TLC_8/OUT_7: TLC9.7 (OUT$7); also elsewhere on the board
/TLC_8/OUT_8: TLC9.8 (OUT$8); also elsewhere on the board
/TLC_8/OUT_9: TLC9.9 (OUT$9); also elsewhere on the board
/TLC_8/OUT_10: TLC9.10 (OUT$10); also elsewhere on the board
/TLC_8/OUT_11: TLC9.11 (OUT$11); also elsewhere on the board
/TLC_8/OUT_12: TLC9.12 (OUT$12); also elsewhere on the board
/TLC_8/OUT_13: TLC9.13 (OUT$13); also elsewhere on the board
/TLC_8/OUT_14: TLC9.14 (OUT$14); also elsewhere on the board
/TLC_8/OUT_15: TLC9.15 (OUT$15); also elsewhere on the board
/TLC_8/SIN: TLC8.17 (SOUT), TLC9.26 (SIN)
/TLC_8/SOUT: TLC9.17 (SOUT); also elsewhere on the board
GND: C2.2, C3.2, C4.2, C5.2, C6.2, C7.2, C8.2, C9.2, R2.1, R3.1, R4.1, R5.1, R6.1, R7.1, R8.1, R9.1, TLC1.22 (GND), TLC2.22 (GND), TLC3.22 (GND), TLC5.22 (GND), TLC6.22 (GND), TLC7.22 (GND), TLC8.22 (GND), TLC9.22 (GND); also elsewhere on the board
unnamed: R2.2, TLC2.20 (IREF)
unnamed: R3.2, TLC3.20 (IREF)
unnamed: R5.2, TLC5.20 (IREF)
unnamed: R6.2, TLC6.20 (IREF)
unnamed: R7.2, TLC7.20 (IREF)
unnamed: R8.2, TLC8.20 (IREF)
unnamed: R9.2, TLC9.20 (IREF)

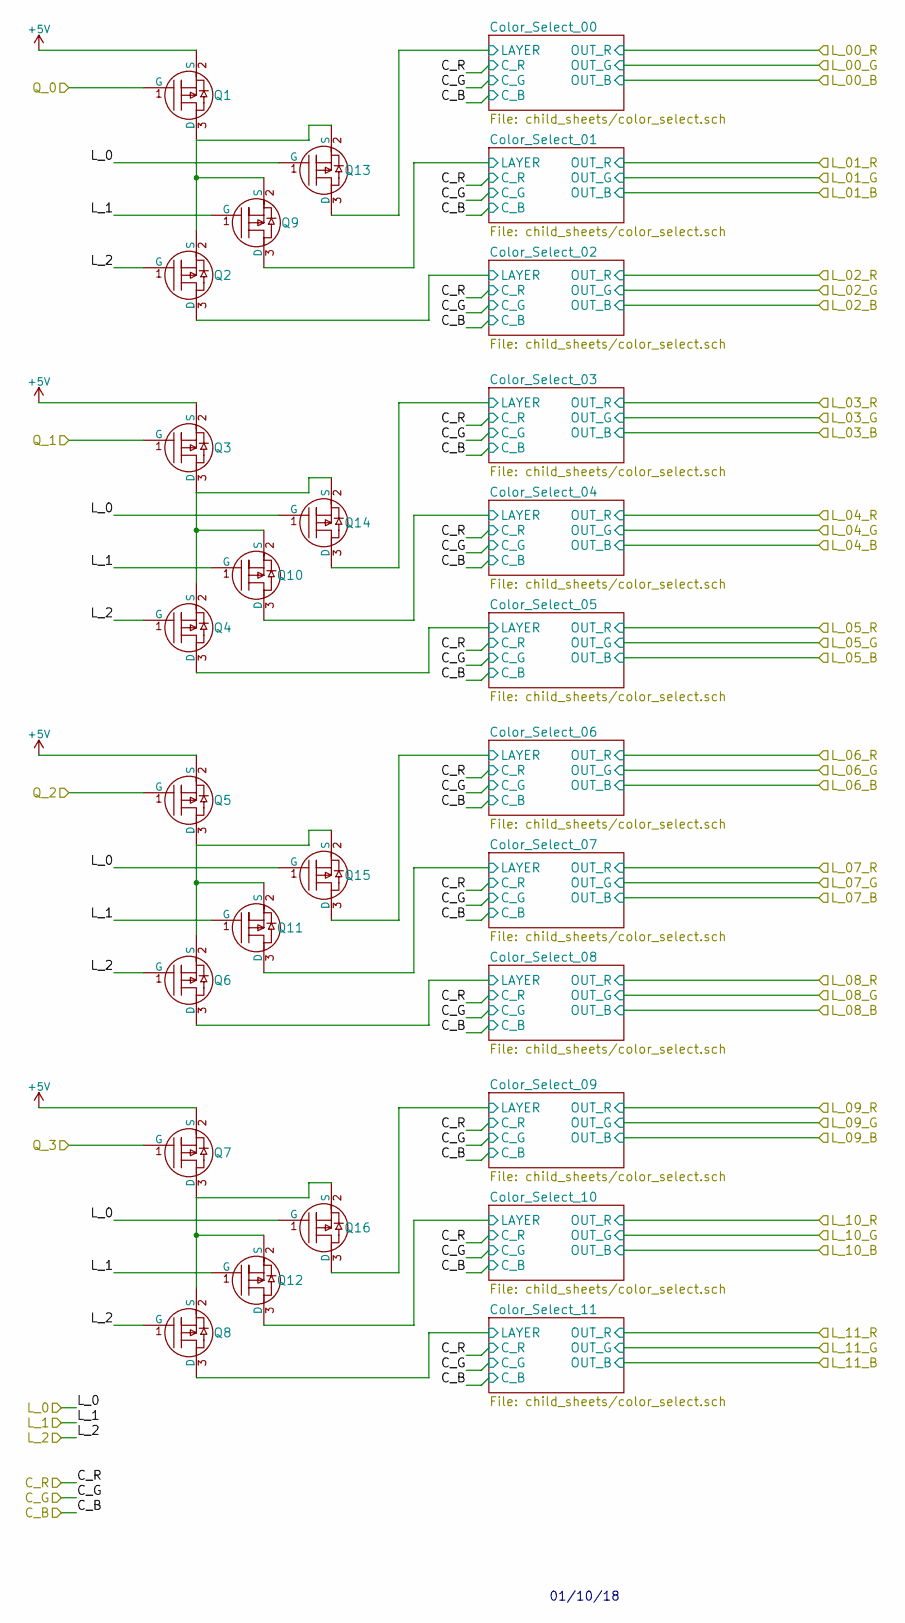
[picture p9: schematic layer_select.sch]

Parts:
Q1, Q2, Q3, Q4, Q5, Q6, Q7, Q8, Q9, Q10, Q11, Q12, Q13, Q14, Q15, Q16: P-Channel_MOSFET; SOT-23

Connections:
+5V: Q1.2 (S), Q3.2 (S), Q5.2 (S), Q7.2 (S); also elsewhere on the board
/Level Shift/OUT_0: Q1.1 (G); also elsewhere on the board
/Level Shift/OUT_1: Q3.1 (G); also elsewhere on the board
/Level Shift/OUT_2: Q5.1 (G); also elsewhere on the board
/Level Shift/OUT_3: Q7.1 (G); also elsewhere on the board
/MOSFET_TREE/Color_Select_00/LAYER: Q13.3 (D); also elsewhere on the board
/MOSFET_TREE/Color_Select_01/LAYER: Q9.3 (D); also elsewhere on the board
/MOSFET_TREE/Color_Select_02/LAYER: Q2.3 (D); also elsewhere on the board
/MOSFET_TREE/Color_Select_03/LAYER: Q14.3 (D); also elsewhere on the board
/MOSFET_TREE/Color_Select_04/LAYER: Q10.3 (D); also elsewhere on the board
/MOSFET_TREE/Color_Select_05/LAYER: Q4.3 (D); also elsewhere on the board
/MOSFET_TREE/Color_Select_06/LAYER: Q15.3 (D); also elsewhere on the board
/MOSFET_TREE/Color_Select_07/LAYER: Q11.3 (D); also elsewhere on the board
/MOSFET_TREE/Color_Select_08/LAYER: Q6.3 (D); also elsewhere on the board
/MOSFET_TREE/Color_Select_09/LAYER: Q16.3 (D); also elsewhere on the board
/MOSFET_TREE/Color_Select_10/LAYER: Q12.3 (D); also elsewhere on the board
/MOSFET_TREE/Color_Select_11/LAYER: Q8.3 (D); also elsewhere on the board
/MOSFET_TREE/L_0: Q13.1 (G), Q14.1 (G), Q15.1 (G), Q16.1 (G); also elsewhere on the board
/MOSFET_TREE/L_1: Q9.1 (G), Q10.1 (G), Q11.1 (G), Q12.1 (G); also elsewhere on the board
/MOSFET_TREE/L_2: Q2.1 (G), Q4.1 (G), Q6.1 (G), Q8.1 (G); also elsewhere on the board
unnamed: Q1.3 (D), Q2.2 (S), Q9.2 (S), Q13.2 (S)
unnamed: Q3.3 (D), Q4.2 (S), Q10.2 (S), Q14.2 (S)
unnamed: Q5.3 (D), Q6.2 (S), Q11.2 (S), Q15.2 (S)
unnamed: Q7.3 (D), Q8.2 (S), Q12.2 (S), Q16.2 (S)

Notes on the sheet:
01/10/18

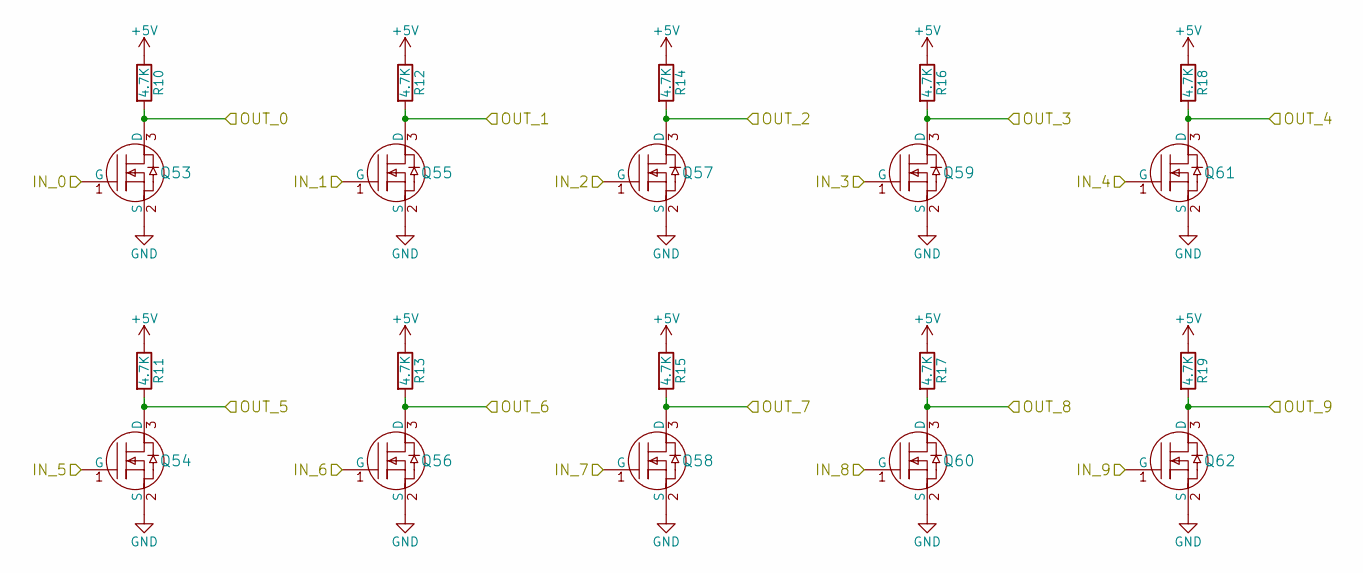
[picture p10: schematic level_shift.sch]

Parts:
Q53, Q54, Q55, Q56, Q57, Q58, Q59, Q60, Q61, Q62: N-Channel_MOSFET; SOT-23
R10, R11, R12, R13, R14, R15, R16, R17, R18, R19: 4.7K; R_0805_HandSoldering

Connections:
+5V: R10.1, R11.1, R12.1, R13.1, R14.1, R15.1, R16.1, R17.1, R18.1, R19.1; also elsewhere on the board
/Level Shift/IN_0: Q53.1 (G); also elsewhere on the board
/Level Shift/IN_1: Q55.1 (G); also elsewhere on the board
/Level Shift/IN_2: Q57.1 (G); also elsewhere on the board
/Level Shift/IN_3: Q59.1 (G); also elsewhere on the board
/Level Shift/IN_4: Q61.1 (G); also elsewhere on the board
/Level Shift/IN_5: Q54.1 (G); also elsewhere on the board
/Level Shift/IN_6: Q56.1 (G); also elsewhere on the board
/Level Shift/IN_7: Q58.1 (G); also elsewhere on the board
/Level Shift/IN_8: Q60.1 (G); also elsewhere on the board
/Level Shift/IN_9: Q62.1 (G); also elsewhere on the board
/Level Shift/OUT_0: Q53.3 (D), R10.2; also elsewhere on the board
/Level Shift/OUT_1: Q55.3 (D), R12.2; also elsewhere on the board
/Level Shift/OUT_2: Q57.3 (D), R14.2; also elsewhere on the board
/Level Shift/OUT_3: Q59.3 (D), R16.2; also elsewhere on the board
/MOSFET_TREE/C_B: Q62.3 (D), R19.2; also elsewhere on the board
/MOSFET_TREE/C_G: Q60.3 (D), R17.2; also elsewhere on the board
/MOSFET_TREE/C_R: Q58.3 (D), R15.2; also elsewhere on the board
/MOSFET_TREE/L_0: Q61.3 (D), R18.2; also elsewhere on the board
/MOSFET_TREE/L_1: Q54.3 (D), R11.2; also elsewhere on the board
/MOSFET_TREE/L_2: Q56.3 (D), R13.2; also elsewhere on the board
GND: Q53.2 (S), Q54.2 (S), Q55.2 (S), Q56.2 (S), Q57.2 (S), Q58.2 (S), Q59.2 (S), Q60.2 (S), Q61.2 (S), Q62.2 (S); also elsewhere on the board

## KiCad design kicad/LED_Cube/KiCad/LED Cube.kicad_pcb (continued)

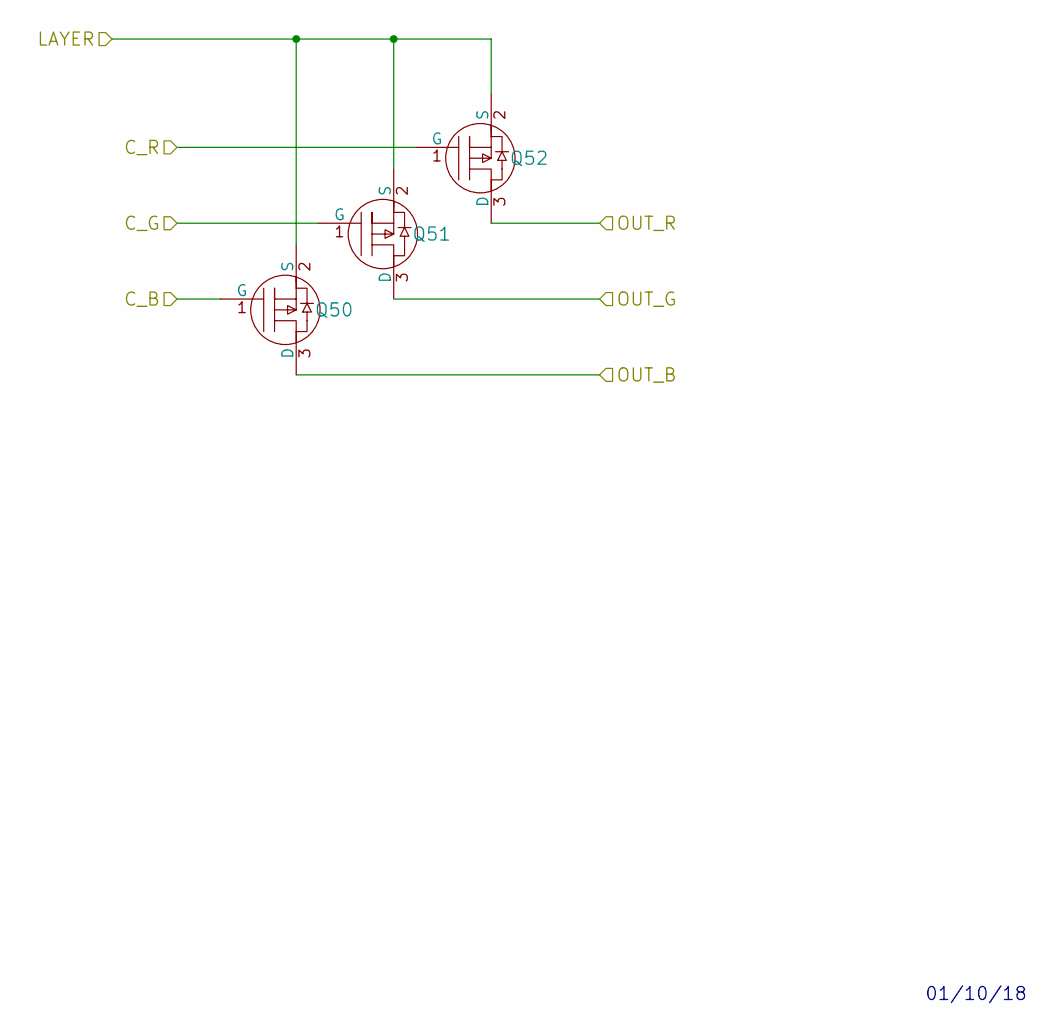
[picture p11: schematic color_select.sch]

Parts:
Q17, Q18, Q19: P-Channel_MOSFET; SOT-23

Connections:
/MOSFET_TREE/C_B: Q17.1 (G); also elsewhere on the board
/MOSFET_TREE/C_G: Q18.1 (G); also elsewhere on the board
/MOSFET_TREE/C_R: Q19.1 (G); also elsewhere on the board
/MOSFET_TREE/Color_Select_00/LAYER: Q17.2 (S), Q18.2 (S), Q19.2 (S); also elsewhere on the board
/MOSFET_TREE/L_00_B: Q17.3 (D); also elsewhere on the board
/MOSFET_TREE/L_00_G: Q18.3 (D); also elsewhere on the board
/MOSFET_TREE/L_00_R: Q19.3 (D); also elsewhere on the board

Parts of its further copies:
Q20, Q21, Q22, Q23, Q24, Q25, Q26, Q27, Q28, Q29, Q30, Q31, Q32, Q33, Q34, Q35, Q36, Q37, Q38, Q39, Q40, Q41, Q42, Q43, Q44, Q45, Q46, Q47, Q48, Q49, Q50, Q51, Q52: P-Channel_MOSFET; SOT-23

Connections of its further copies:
/MOSFET_TREE/C_B: Q20.1 (G), Q23.1 (G), Q26.1 (G), Q29.1 (G), Q32.1 (G), Q35.1 (G), Q38.1 (G), Q41.1 (G), Q44.1 (G), Q47.1 (G), Q50.1 (G); also elsewhere on the board
/MOSFET_TREE/C_G: Q21.1 (G), Q24.1 (G), Q27.1 (G), Q30.1 (G), Q33.1 (G), Q36.1 (G), Q39.1 (G), Q42.1 (G), Q45.1 (G), Q48.1 (G), Q51.1 (G); also elsewhere on the board
/MOSFET_TREE/C_R: Q22.1 (G), Q25.1 (G), Q28.1 (G), Q31.1 (G), Q34.1 (G), Q37.1 (G), Q40.1 (G), Q43.1 (G), Q46.1 (G), Q49.1 (G), Q52.1 (G); also elsewhere on the board
/MOSFET_TREE/Color_Select_01/LAYER: Q20.2 (S), Q21.2 (S), Q22.2 (S); also elsewhere on the board
/MOSFET_TREE/Color_Select_02/LAYER: Q23.2 (S), Q24.2 (S), Q25.2 (S); also elsewhere on the board
/MOSFET_TREE/Color_Select_03/LAYER: Q26.2 (S), Q27.2 (S), Q28.2 (S); also elsewhere on the board
/MOSFET_TREE/Color_Select_04/LAYER: Q29.2 (S), Q30.2 (S), Q31.2 (S); also elsewhere on the board
/MOSFET_TREE/Color_Select_05/LAYER: Q32.2 (S), Q33.2 (S), Q34.2 (S); also elsewhere on the board
/MOSFET_TREE/Color_Select_06/LAYER: Q35.2 (S), Q36.2 (S), Q37.2 (S); also elsewhere on the board
/MOSFET_TREE/Color_Select_07/LAYER: Q38.2 (S), Q39.2 (S), Q40.2 (S); also elsewhere on the board
/MOSFET_TREE/Color_Select_08/LAYER: Q41.2 (S), Q42.2 (S), Q43.2 (S); also elsewhere on the board
/MOSFET_TREE/Color_Select_09/LAYER: Q44.2 (S), Q45.2 (S), Q46.2 (S); also elsewhere on the board
/MOSFET_TREE/Color_Select_10/LAYER: Q47.2 (S), Q48.2 (S), Q49.2 (S); also elsewhere on the board
/MOSFET_TREE/Color_Select_11/LAYER: Q50.2 (S), Q51.2 (S), Q52.2 (S); also elsewhere on the board
/MOSFET_TREE/L_01_B: Q20.3 (D); also elsewhere on the board
/MOSFET_TREE/L_01_G: Q21.3 (D); also elsewhere on the board
/MOSFET_TREE/L_01_R: Q22.3 (D); also elsewhere on the board
/MOSFET_TREE/L_02_B: Q23.3 (D); also elsewhere on the board
/MOSFET_TREE/L_02_G: Q24.3 (D); also elsewhere on the board
/MOSFET_TREE/L_02_R: Q25.3 (D); also elsewhere on the board
/MOSFET_TREE/L_03_B: Q26.3 (D); also elsewhere on the board
/MOSFET_TREE/L_03_G: Q27.3 (D); also elsewhere on the board
/MOSFET_TREE/L_03_R: Q28.3 (D); also elsewhere on the board
/MOSFET_TREE/L_04_B: Q29.3 (D); also elsewhere on the board
/MOSFET_TREE/L_04_G: Q30.3 (D); also elsewhere on the board
/MOSFET_TREE/L_04_R: Q31.3 (D); also elsewhere on the board
/MOSFET_TREE/L_05_B: Q32.3 (D); also elsewhere on the board
/MOSFET_TREE/L_05_G: Q33.3 (D); also elsewhere on the board
/MOSFET_TREE/L_05_R: Q34.3 (D); also elsewhere on the board
/MOSFET_TREE/L_06_B: Q35.3 (D); also elsewhere on the board
/MOSFET_TREE/L_06_G: Q36.3 (D); also elsewhere on the board
/MOSFET_TREE/L_06_R: Q37.3 (D); also elsewhere on the board
/MOSFET_TREE/L_07_B: Q38.3 (D); also elsewhere on the board
/MOSFET_TREE/L_07_G: Q39.3 (D); also elsewhere on the board
/MOSFET_TREE/L_07_R: Q40.3 (D); also elsewhere on the board
/MOSFET_TREE/L_08_B: Q41.3 (D); also elsewhere on the board
/MOSFET_TREE/L_08_G: Q42.3 (D); also elsewhere on the board
/MOSFET_TREE/L_08_R: Q43.3 (D); also elsewhere on the board
/MOSFET_TREE/L_09_B: Q44.3 (D); also elsewhere on the board
/MOSFET_TREE/L_09_G: Q45.3 (D); also elsewhere on the board
/MOSFET_TREE/L_09_R: Q46.3 (D); also elsewhere on the board
/MOSFET_TREE/L_10_B: Q47.3 (D); also elsewhere on the board
/MOSFET_TREE/L_10_G: Q48.3 (D); also elsewhere on the board
/MOSFET_TREE/L_10_R: Q49.3 (D); also elsewhere on the board
/MOSFET_TREE/L_11_B: Q50.3 (D); also elsewhere on the board
/MOSFET_TREE/L_11_G: Q51.3 (D); also elsewhere on the board
/MOSFET_TREE/L_11_R: Q52.3 (D); also elsewhere on the board

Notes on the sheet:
01/10/18

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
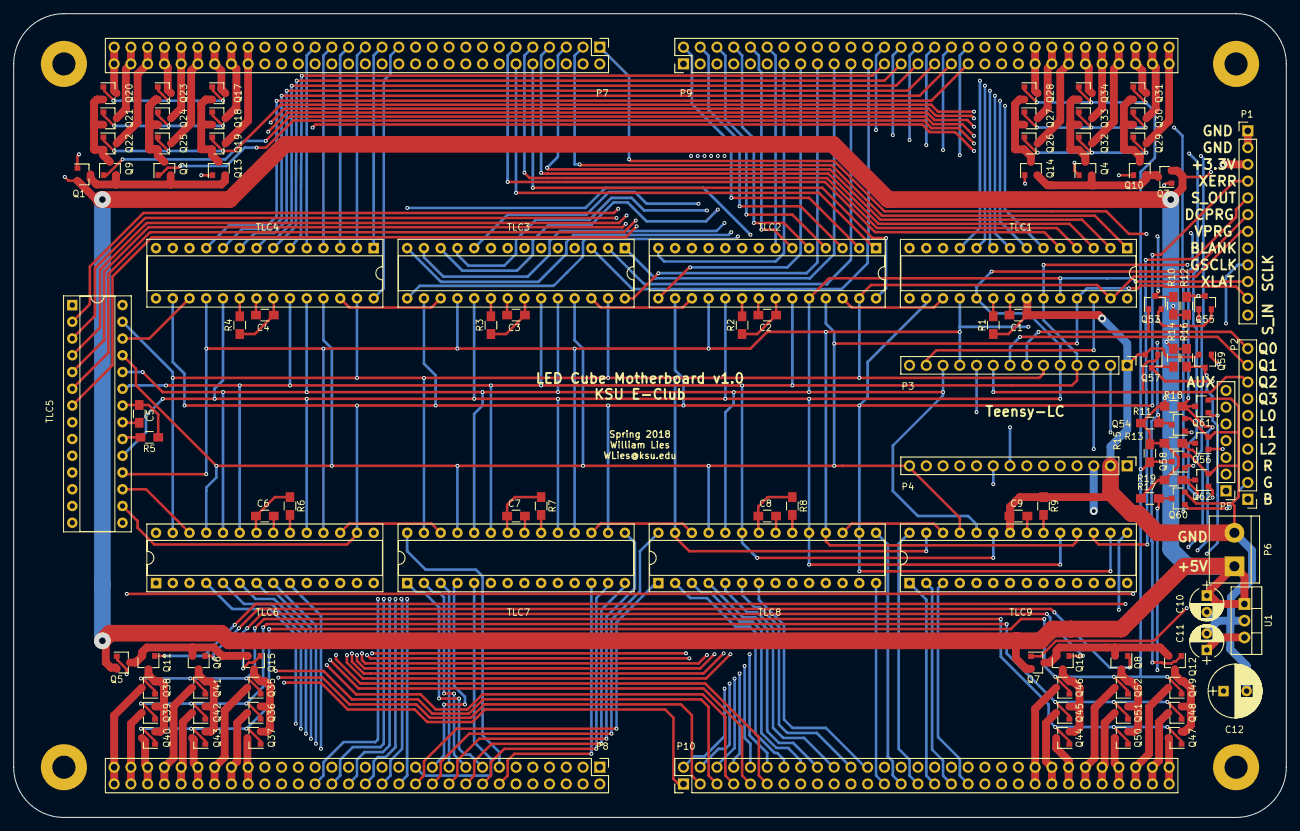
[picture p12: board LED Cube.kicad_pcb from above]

Board: 4 copper layers, 193.0 x 121.9 mm, 113 parts (0 on the bottom side), 252 nets.

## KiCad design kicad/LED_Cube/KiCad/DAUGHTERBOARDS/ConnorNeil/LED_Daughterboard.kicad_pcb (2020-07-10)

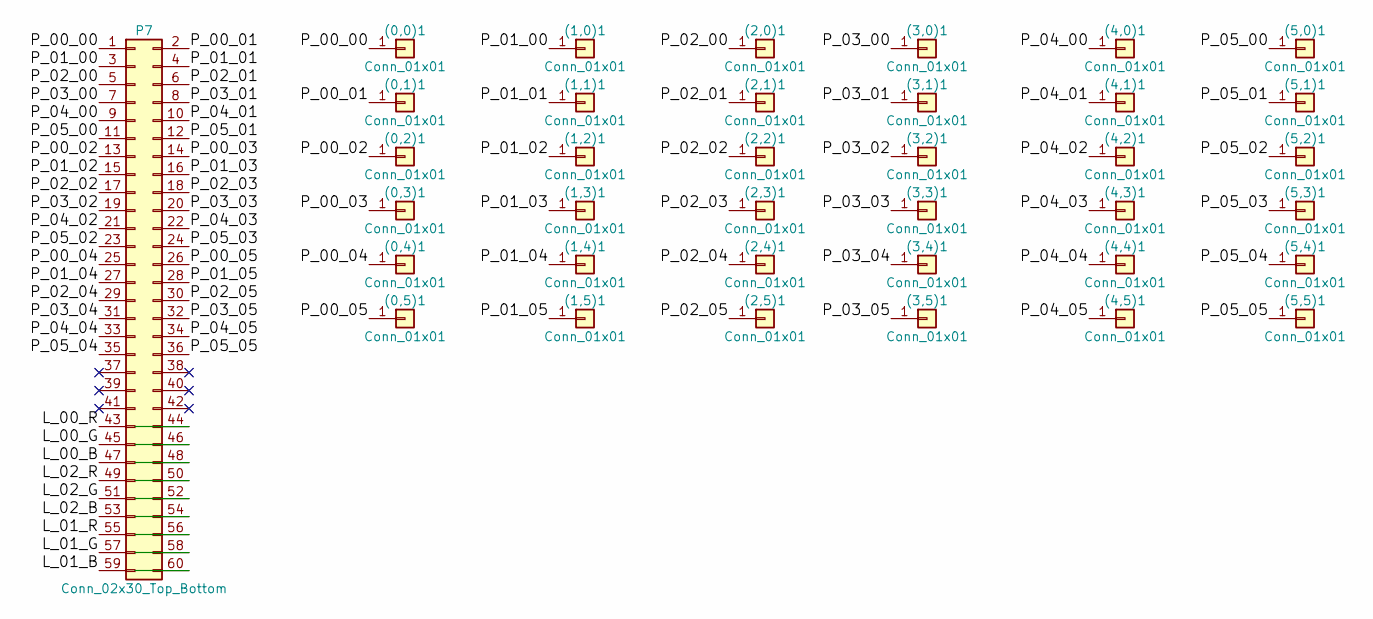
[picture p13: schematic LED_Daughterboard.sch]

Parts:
(0,0)1, (0,1)1, (0,2)1, (0,3)1, (0,4)1, (0,5)1, (1,0)1, (1,1)1, (1,2)1, (1,3)1, (1,4)1, (1,5)1, (2,0)1, (2,1)1, (2,2)1, (2,3)1, (2,4)1, (2,5)1, (3,0)1, (3,1)1, (3,2)1, (3,3)1, (3,4)1, (3,5)1, (4,0)1, (4,1)1, (4,2)1, (4,3)1, (4,4)1, (4,5)1, (5,0)1, (5,1)1, (5,2)1, (5,3)1, (5,4)1, (5,5)1: Conn_01x01; Pin_Header_Straight_1x01_Pitch2.54mm
P7: Conn_02x30_Top_Bottom; Pin_Header_Straight_2x30_Pitch2.54mm

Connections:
/L_00_B: P7.47
/L_00_G: P7.45
/L_00_R: P7.43
/L_01_B: P7.59
/L_01_G: P7.57
/L_01_R: P7.55
/L_02_B: P7.53
/L_02_G: P7.51
/L_02_R: P7.49
/P_00_00: (0,0)1.1, P7.1
/P_00_01: (0,1)1.1, P7.2
/P_00_02: (0,2)1.1, P7.13
/P_00_03: (0,3)1.1, P7.14
/P_00_04: (0,4)1.1, P7.25
/P_00_05: (0,5)1.1, P7.26
/P_01_00: (1,0)1.1, P7.3
/P_01_01: (1,1)1.1, P7.4
/P_01_02: (1,2)1.1, P7.15
/P_01_03: (1,3)1.1, P7.16
/P_01_04: (1,4)1.1, P7.27
/P_01_05: (1,5)1.1, P7.28
/P_02_00: (2,0)1.1, P7.5
/P_02_01: (2,1)1.1, P7.6
/P_02_02: (2,2)1.1, P7.17
/P_02_03: (2,3)1.1, P7.18
/P_02_04: (2,4)1.1, P7.29
/P_02_05: (2,5)1.1, P7.30
/P_03_00: (3,0)1.1, P7.7
/P_03_01: (3,1)1.1, P7.8
/P_03_02: (3,2)1.1, P7.19
/P_03_03: (3,3)1.1, P7.20
/P_03_04: (3,4)1.1, P7.31
/P_03_05: (3,5)1.1, P7.32
/P_04_00: (4,0)1.1, P7.9
/P_04_01: (4,1)1.1, P7.10
/P_04_02: (4,2)1.1, P7.21
/P_04_03: (4,3)1.1, P7.22
/P_04_04: (4,4)1.1, P7.33
/P_04_05: (4,5)1.1, P7.34
/P_05_00: (5,0)1.1, P7.11
/P_05_01: (5,1)1.1, P7.12
/P_05_02: (5,2)1.1, P7.23
/P_05_03: (5,3)1.1, P7.24
/P_05_04: (5,4)1.1, P7.35
/P_05_05: (5,5)1.1, P7.36

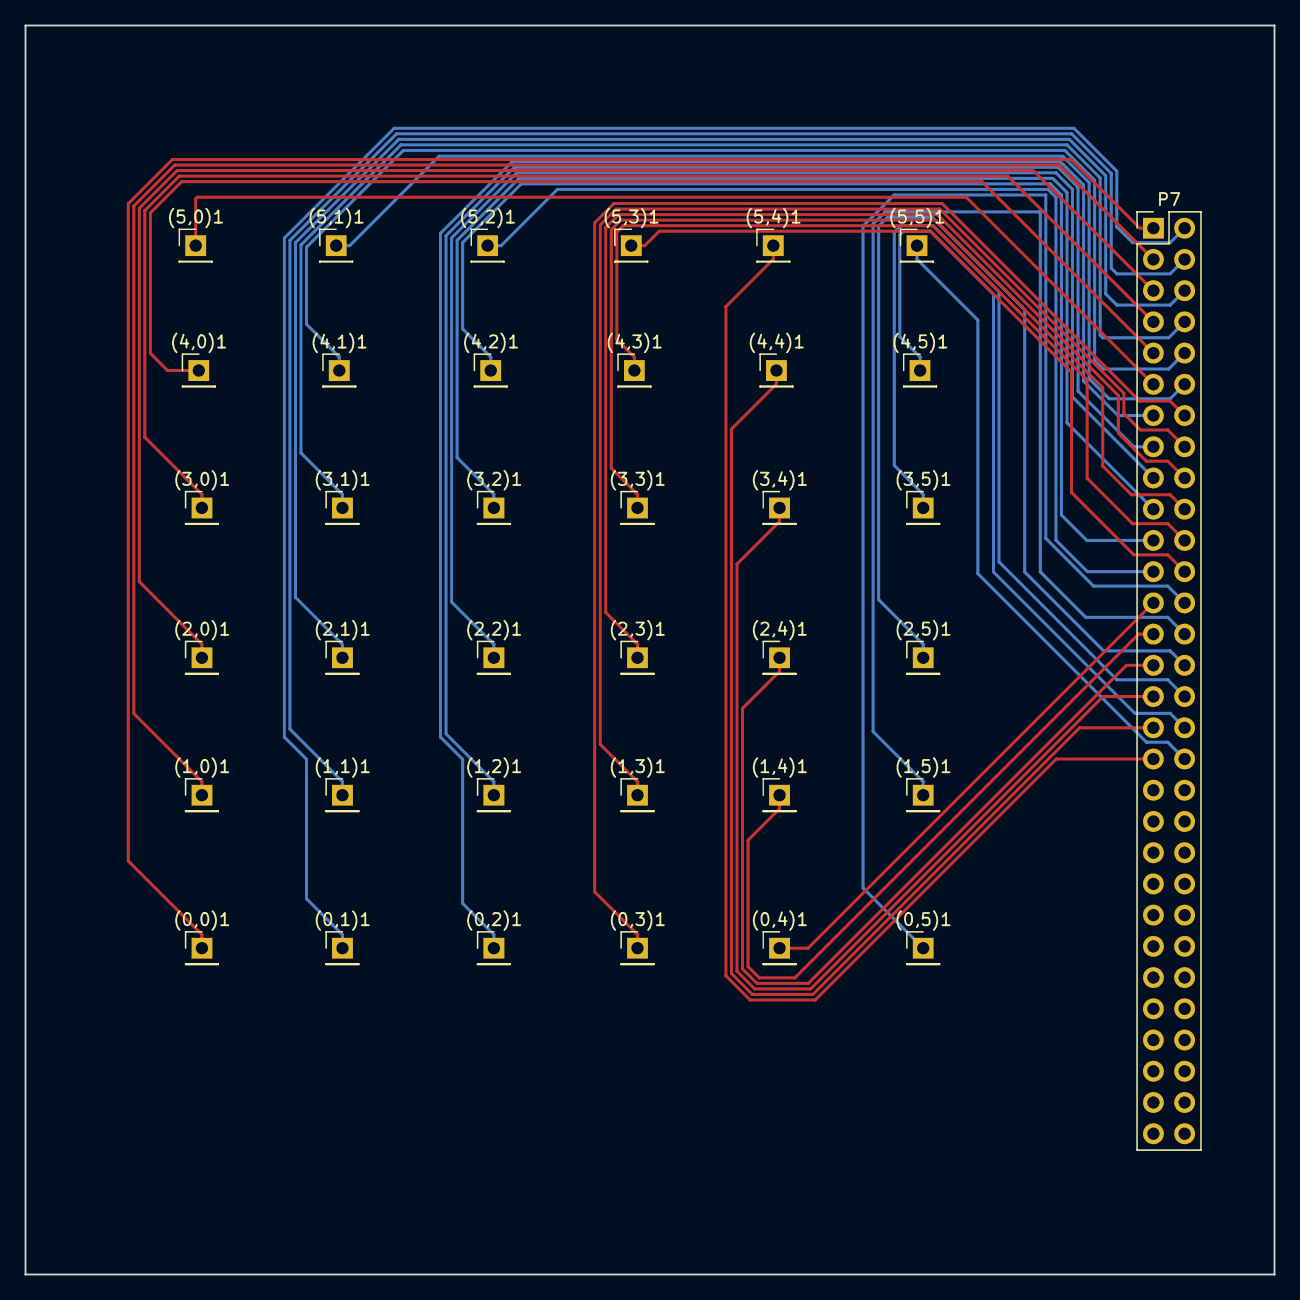
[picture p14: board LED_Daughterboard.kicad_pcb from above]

Board: 2 copper layers, 101.6 x 101.6 mm, 37 parts (0 on the bottom side), 36 nets.

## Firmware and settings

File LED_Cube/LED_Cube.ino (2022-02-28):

#include <PS2Keyboard.h>
#include "SPI.h"
#include "TLC_lib.h"
#include "MUX_lib.h"

// Core library for code-sense - IDE-based
#if defined(ENERGIA) // LaunchPad specific
#include "Energia.h"
#elif defined(TEENSYDUINO) // Teensy specific
#include "Arduino.h"
#elif defined(ESP8266) // ESP8266 specific
#include "Arduino.h"
#elif defined(ARDUINO) // Arduino 1.8 specific
#include "Arduino.h"
#else // error
#error Platform not defined
#endif // end IDE

volatile uint8_t     gs_buf[NUM_BYTES];  //Buffer written to TLCs over SPI (12 bit color values)
volatile uint16_t    px_buf[NUM_LEDS];   //Pixel buffer storing each LED color as a 16 bit value ( RRRRRGGGGGGBBBBB )

#include <math.h>
#include "PS2Keyboard.h"
#include "src/Tools/Input/Input.h"
#include "src/LED_Cube_library/globals.h"
#include "src/Tools/OS/Menu.h"
#include "src/Apps/App_Includes.h"
#include "src/Apps/Animations/Wave2.0.h"
#include "src/Apps/App.h"
#include "src/Tools/MathObjects/UltamateTrigLookUp.h"

// just no, no, no. This must be exterminated
uint16_t white = 0xFFFF;

// setup function
void setup()
{
    delay(1000);

    // only one will be victorious....
    Input::keyboard.begin(15, 21);

    delay(200);
    mux_init();
    init_TLC();
    memset((uint8_t *)gs_buf, 0xFF, NUM_BYTES);
    delay(100);
    write_dot_correction((uint8_t *)gs_buf);
    memset((uint8_t *)gs_buf, 0x00, NUM_BYTES);
    memset((uint16_t *)px_buf, 0x0000, NUM_LEDS * 2);
    mux_begin();
    delay(200);

    pinMode(23, OUTPUT);
    digitalWrite(23, HIGH);
}

/**************************************************************************
 *
 *
 *
 *  The loop call
 *
 *
 *
 **************************************************************************/
void loop()
{
    // TypeEngine::autoTypeUpper("Hello jacob", 0x003F, 0xFD00); 
    // TypeEngine::autoTypeLower("    this is test", 0x000F, 0xF000); 
    // delay(1000);
    // return;
    // App* app = App::Ctor<Snow>();
    // app->run();
    AppCtor stuff[] = {
        App::Ctor<Wave>, App::Ctor<Swirl>, App::Ctor<Wave>, App::Ctor<Space>, App::Ctor<Snow>
    };
    AppCtor Apps[] = {
        App::Ctor<Snake>, App::Ctor<Dodge>
    };
     AppCtor* screenSaver = stuff;
    // creation of the menu application 
     Menu menu = Menu(Apps, 2, screenSaver, 5);
    menu.run(); // thats all folks
} //end loop

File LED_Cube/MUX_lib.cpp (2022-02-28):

//
// MUX_lib.cpp
// C++ code
// ----------------------------------
// Developed with embedXcode
// http://embedXcode.weebly.com
//
// Project 		0_LED_Cube
//
// Created by 	William Lies, 10/21/17 9:56 AM
// 				William Lies
//
// Copyright 	(c) William Lies, 2017
// Licence		licence
//
//


/*------------------------------------------------------
 *  Automatic Includes
 -----------------------------------------------------*/

/*------------------------------------------------------
 *  User Includes
 -----------------------------------------------------*/
#include "MUX_lib.h"
#include "TLC_lib.h"
/*------------------------------------------------------
 * Constants
 -----------------------------------------------------*/
enum{
    VAL_R = 0,
    VAL_G = 1,
    VAL_B = 2
};

/*------------------------------------------------------
 * Variables
 -----------------------------------------------------*/
extern volatile uint8_t     gs_buf[NUM_BYTES];   //Declared in the main .ino
extern volatile uint16_t    px_buf[NUM_LEDS];

IntervalTimer per_int;          //Object to set up periodic timer interrupt

volatile uint8_t    cur_q;      //Tracks what quarter we're on
volatile uint8_t    cur_l;      //Tracks what physical layer we're on
volatile uint8_t    cur_c;      //Tracks what color layer we're on
volatile uint8_t    next_q;      //next quarter (for pre-loading of gs_buf)
volatile uint8_t    next_l;      //next layer (for pre-loading of gs_buf)
volatile uint8_t    next_c;      //next color (for pre-loading of gs_buf)
static const uint8_t pins_q[NUM_P_Q] = { P_Q_0, P_Q_1, P_Q_2, P_Q_3 };
static const uint8_t pins_l[NUM_P_L] = { P_L_0, P_L_1, P_L_2 };
static const uint8_t pins_c[NUM_P_C] = { P_C_R, P_C_G, P_C_B };


/*------------------------------------------------------
 *  Funciton Definitions
 -----------------------------------------------------*/

//Initializes all the pins and variables used for multiplexing
void mux_init(){

    
    pinMode(P_Q_0, OUTPUT);
    pinMode(P_Q_1, OUTPUT);
    pinMode(P_Q_2, OUTPUT);
    pinMode(P_Q_3, OUTPUT);
    pinMode(P_L_0, OUTPUT);
    pinMode(P_L_1, OUTPUT);
    pinMode(P_L_2, OUTPUT);
    pinMode(P_C_R, OUTPUT);
    pinMode(P_C_G, OUTPUT);
    pinMode(P_C_B, OUTPUT);
    
    digitalWriteFast(P_Q_0, LOW);
    digitalWriteFast(P_Q_1, LOW);
    digitalWriteFast(P_Q_2, LOW);
    digitalWriteFast(P_Q_3, LOW);
    digitalWriteFast(P_L_0, LOW);
    digitalWriteFast(P_L_1, LOW);
    digitalWriteFast(P_L_2, LOW);
    digitalWriteFast(P_C_R, LOW);
    digitalWriteFast(P_C_G, LOW);
    digitalWriteFast(P_C_B, LOW);
    
    cur_q = 0;
    cur_l = 0;
    cur_c = 0;
    next_q = 0;
    next_l = 0;
    next_c = 0;
}


//Starts the timer interrupt for multiplexing
void mux_begin(){
    //Start timer interrupt
    per_int.priority(0xFF);
    per_int.begin(mux_isr, 500); //4096 cycles at 12 MHz is 342us.
}



//Multiplexing Interrupt Service Routine (ISR)
//This function is called periodically via the timer interrupt.
//This function switches the multiplexing FETs and writes data to the TLCs.
//First, the values for the next layer are computed, then they are all written at once (at CHANGE ACTIVE LAYER)
//This approach avoids turning off the leds while we wait for data transfers and such.
void mux_isr(){
interrupts();

    
    //find next quarter, layer, and color
    next_c = cur_c + 1;
    if( next_c >= NUM_P_C ){
        next_c = 0;
        next_l = cur_l + 1;
        if( next_l >= NUM_P_L ){
            next_l = 0;
            next_q = cur_q + 1;
            if( next_q >= NUM_P_Q ){
                next_q = 0;
            }
        }
    }
    
    //Transfer data from the pixel buffer to the grayscale buffer
    int led_idx_ofs = NUM_LEDS_LYR * ((int)next_q * NUM_P_L + (int)next_l);   //LED index offset
    for(int i=0; i<NUM_LEDS_LYR; i++){                                  //Iterate through each LED in the layer
        set_channel(    i,  //set the ith channel of the 144 available channels
                        //find the color value for the ith LED in the current layer
                        extract_color( px_buf[led_idx_ofs + i], next_c ),
                        (uint8_t*)gs_buf );
    }
    
    
    
    /* CHANGE ACTIVE LAYER */       //Please excuse the unorthodox formatting.
                           digitalWriteFast( pins_c[cur_c], LOW );      //Turn off all the current FET pins
    if( cur_l != next_l ){ digitalWriteFast( pins_l[cur_l], LOW ); }
    digitalWriteFast( pins_q[cur_q], LOW );
    
    if( cur_l != next_l ){ digitalWriteFast( pins_l[next_l], HIGH ); } //Turn on the next FET pins
                           digitalWriteFast( pins_c[next_c], HIGH );

    write_grey_scale((uint8_t*)gs_buf);         //Write the grayscale buffer
    
    digitalWriteFast( pins_q[next_q], HIGH );
    
    
    cur_l = next_l;     //update the current counters
    cur_q = next_q;
    cur_c = next_c;

    
}


//Extracts a "12-bit" (0-4096) color value from a 16-bit number packed (RRRR RGGG GGGB BBBB)
uint16_t extract_color( uint16_t bits, uint8_t color ){
    switch( color ){
        case VAL_R:
            if( (bits & 0xF800) == 0 ){ return 0; } //return 0 if it's all 0
            return ( bits | 0x07FF )>>4; //return R value with ones at end
            break;
        case VAL_G:
            if( (bits & 0x07E0) == 0 ){ return 0; }
            return ( (bits << 5) | 0x03FF )>>4;
            break;
        default: //VAL_B
            if( (bits & 0x001F) == 0 ){ return 0; }
            return ( (bits << 11) | 0x07FF )>>4;
    }
}

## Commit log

2019-06-05 Update TeensyTest.ino
    Addded start of pong
2019-08-24 Revert back to github from bitbucket
    [TeensyTest.ino]
2019-08-30 Fixed some things and other stuff
    [TeensyTest.ino]
2020-07-10 This adds the kicad files, and adds relativistic to the tools
    [LED Cube.kicad_pcb, LED Cube.sch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]
2022-02-28 Did more
    [LED Cube.kicad_pcb, LED Cube.sch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]
